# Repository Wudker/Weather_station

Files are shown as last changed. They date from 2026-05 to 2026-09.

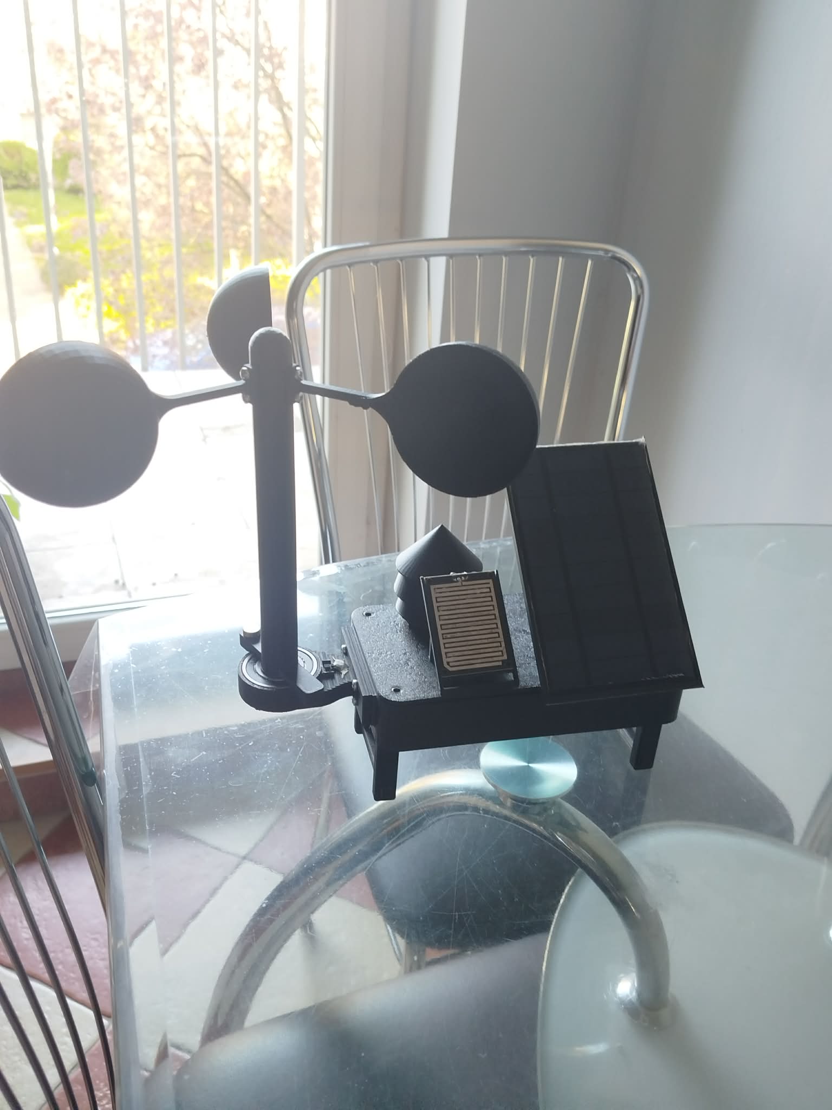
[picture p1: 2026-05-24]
Hardware/Photos/real_model.jpg

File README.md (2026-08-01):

# ESP32 Solar Weather Station

ESP32 Solar Weather Station is a solar-assisted environmental monitoring system consisting of an outdoor measurement module and an indoor receiver. The outdoor unit periodically measures temperature, humidity, atmospheric pressure, wind speed, rainfall, battery voltage and solar-panel voltage. The collected data is transmitted via ESP-NOW to the receiver, which presents current measurements and recent trends through a local web dashboard. RTC-controlled wake-up and sleep modes reduce energy consumption, while a Li-Ion battery and photovoltaic panel support long-term outdoor operation.

## Technologies

`ESP32` `C/C++` `ESP-NOW` `BME280` `SS41F Hall sensor` `Rain sensor` `RTC` `Li-Ion battery` `Photovoltaic power` `ESP32 WebServer` `Low-power operation`

## Usage and development status

Configure the wireless and network parameters, then upload the appropriate firmware to the outdoor and receiver ESP32 modules. After starting both devices, measurements can be accessed through the receiver's local web interface. The current prototype is functional and has been tested; planned improvements include a custom PCB, better enclosure sealing, optimized power management and expanded data visualization.

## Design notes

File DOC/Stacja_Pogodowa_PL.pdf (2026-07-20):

# Projekt „Pogodynka”

Dokumentacja koncowa prototypu ´

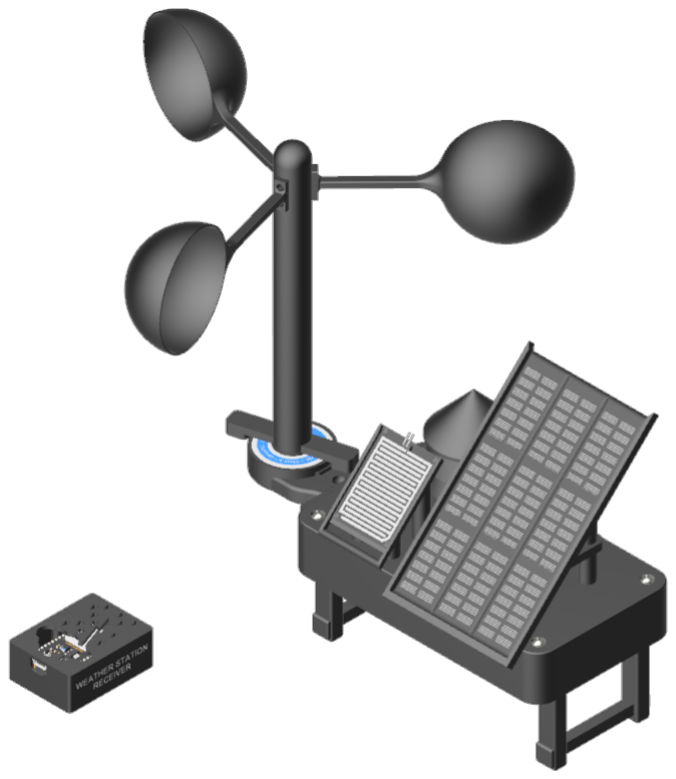
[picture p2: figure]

Autor | Inz. Bartłomiej Dusza ˙
Rewizja | Rev. A
Data | 20 kwietnia 2026
Wersja | 1.0

Niniejszy dokument stanowi podsumowanie etapu realizacji prototypu stacji pogodowej oraz opis jego załoze˙ n, budowy, działania i kierunku dalszego rozwoju. ´

# Spis tresci ´

1 Zało˙zenia projektu | 2
2 Wykonanie prototypu | 6
3 Oprogramowanie i działanie systemu | 9
3.4 Interfejs uzytkownika | ˙ | 10
4 Walidacja prototypu | 11
5 Wnioski i kierunek rozwoju | 12
5.1 Wnioski koncowe | ´ | 12

# Zało˙zenia projektu

## 1.1 Idea i cel urz ˛adzenia

Celem projektu było opracowanie prototypu niewielkiej stacji pogodowej przeznaczonej do pracy zewn˛etrznej, zdolnej do okresowego pomiaru podstawowych parametrów srodowiskowych oraz bezprzewodowego przesyłania wyników do odbiornika. ´

Załozenie projektowe obejmowało wykonanie dwóch współpracuj ˛acych cz˛e ˙ | sci systemu: ´
- modułu pomiarowego umieszczanego na zewn ˛atrz,
- modułu odbiorczego prezentuj ˛acego dane w lokalnej sieci.

Istotnym wymaganiem projektu była mozliwie energooszcz˛edna praca układu oraz ˙ mozliwo ˙ s´c jego dalszej rozbudowy w kolejnych iteracjach. ´

## 1.2 Schemat blokowy systemu

Na rysunku 1.1 przedstawiono ogólny schemat blokowy projektowanego systemu.

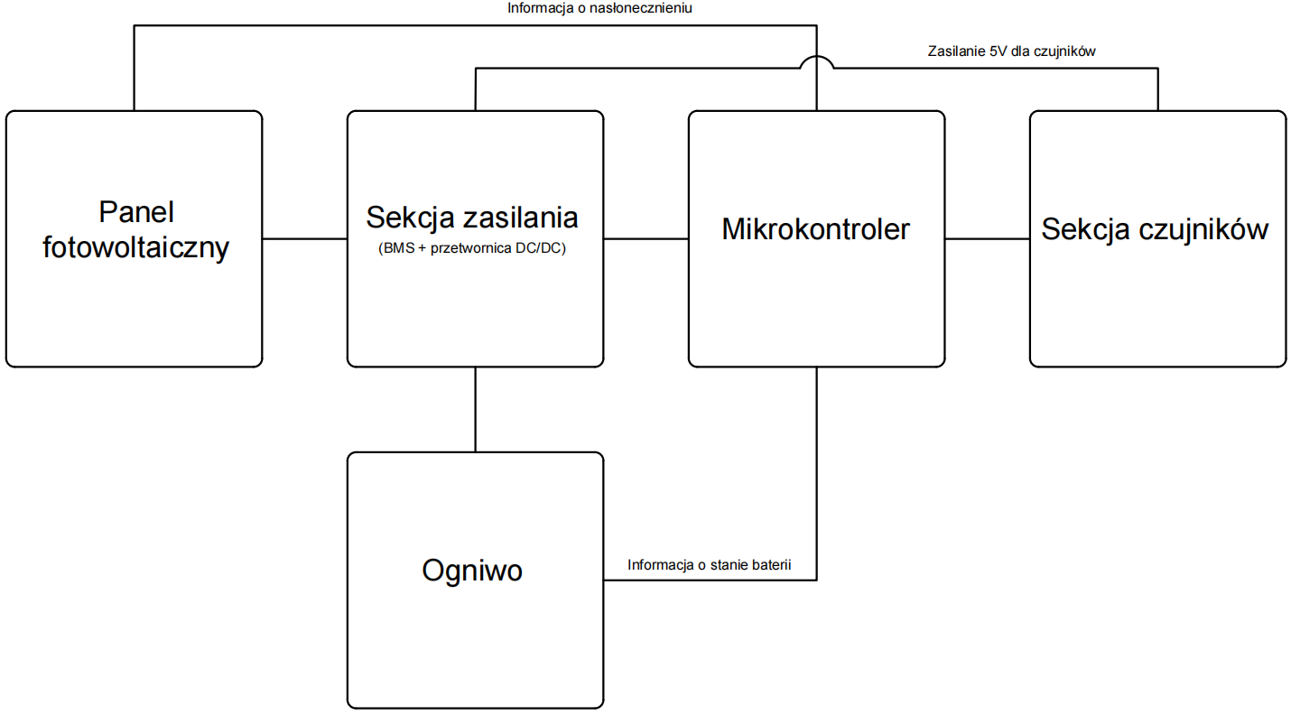
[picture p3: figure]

Rysunek 1.1: Schemat blokowy systemu.

Układ składa si˛e z cz˛esci pomiarowej, modułu steruj ˛acego, toru zasilania oraz cz˛e ´ | sci ´
odbiorczej. Czujniki srodowiskowe s ˛a odczytywane przez mikrokontroler ESP32, który ´

po wykonaniu pomiaru przygotowuje pakiet danych i przesyła go do odbiornika przy pomocy protokołu ESP-NOW. Odbiornik udost˛epnia wyniki w postaci prostej strony internetowej dost˛epnej w sieci lokalnej.

## 1.3 Dobór modułów

Stacja pogodowa musiała umozliwia ˙ | c pomiar podstawowych parametrów atmosferycz- ´
nych, a takze współpracowa ˙ | c z układem zasilanym z ogniwa i panelu fotowoltaicznego. ´
Z tego wzgl˛edu dobrano moduły przedstawione w tabeli 1.1.

Tabela 1.1: Zastosowane moduły i ich funkcje.

Moduł | Funkcja | Interfejs / spo-
sób pracy

Powód wyboru

BME280 | pomiar temperatury,
wilgotnosci i ci ´ | snienia ´

I

2C | integracja trzech
pomiarów w jednym układzie
SGP40 | ocena jakosci powie- ´
trza

I

2C | mozliwo ˙ | s´c rozsze- ´
rzenia funkcjonalnosci o VOC ´
SS41F | pomiar impulsów ane-
mometru
wyjscie cyfrowe ´ | prosty pomiar
pr˛edkosci wiatru ´
Czujnik deszczu | wykrywanie opadów | wyjscie analo- ´
gowe/cyfrowe

niski koszt i łatwos´c integracji ´
ESP32 | sterowanie i transmi-
sja danych

Wi-Fi/ESP-NOW komunikacja bezprzewodowa i wygodna integracja
RTC | wybudzanie czasowe I²C | precyzyjne plano-
wanie cyklu pracy
Panel fotowoltaiczny
zasilanie pomocnicze ´zródło energii | cz˛esciowa samo- ´
wystarczalnos´c´
układu
TP4056 / moduł zasilania
ładowanie ogniwa | tor zasilania | prostota prototy-
powania

### Czujniki srodowiskowe ´

Jako podstawowy sensor srodowiskowy wybrano BME280, który umo ´ | zliwia jednoczesny ˙
pomiar temperatury, wilgotnosci oraz ci ´ | snienia atmosferycznego. ´

Zastosowanie jednego układu do realizacji trzech pomiarów uprosciło konstrukcj˛e oraz ´ ograniczyło liczb˛e poł ˛aczen. Jako uzupełnienie zestawu czujników dobrano SGP40 ´ do oceny jakosci powietrza oraz czujnik Halla SS41F, wykorzystywany do pomiaru ´ pr˛edkosci wiatru na podstawie impulsów generowanych przez obracaj ˛acy si˛e element ´ anemometru.

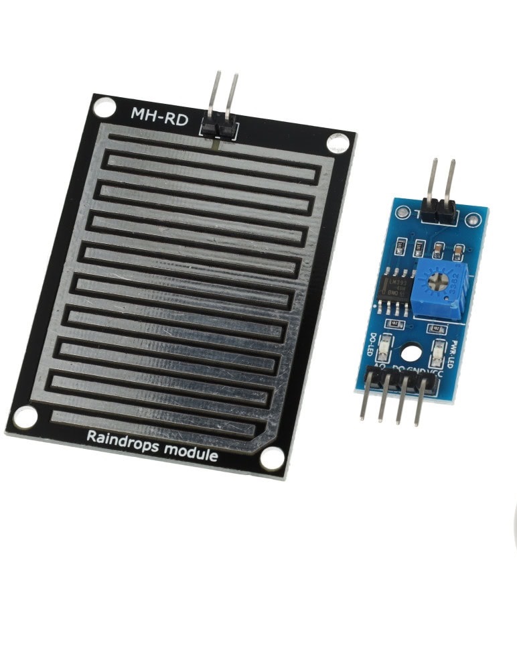
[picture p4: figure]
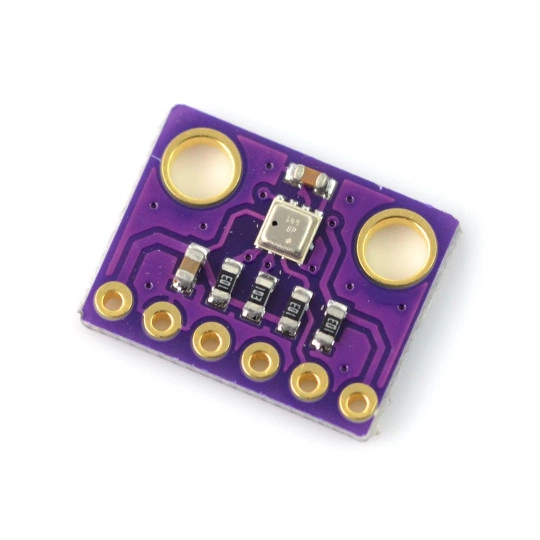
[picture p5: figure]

(a) Moduł czujnika BME280. | (b) Moduł czujnika deszczu.

Rysunek 1.2: Uzupełniaj ˛ace moduły pomiarowe.

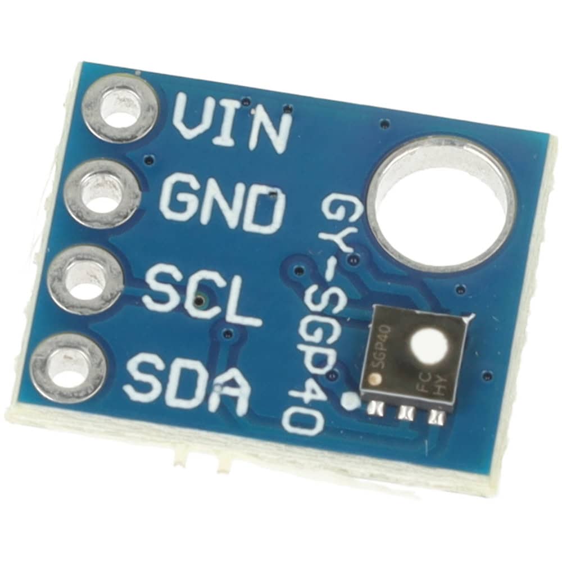
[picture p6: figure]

(a) Moduł SGP40. | (b) Czujnik Halla SS41F.

Rysunek 1.3: Uzupełniaj ˛ace moduły pomiarowe.

Dla mozliwo ˙ | sci wykrywania opadów wykorzystano prosty moduł czujnika deszczu umo ´ | z-˙
liwiaj ˛acy zarówno cyfrow ˛a, jak i analogow ˛a ocen˛e zawilgocenia powierzchni pomiarowej.

### Moduły steruj ˛ace i pomocnicze

Jako główny mikrokontroler zastosowano ESP32, którego zalet ˛a była mozliwo ˙ s´c bez- ´ przewodowej transmisji danych oraz wygodna współpraca z pozostałymi elementami systemu. W celu dokładniejszego planowania cykli pracy układu zastosowano takze˙ zewn˛etrzny moduł RTC.

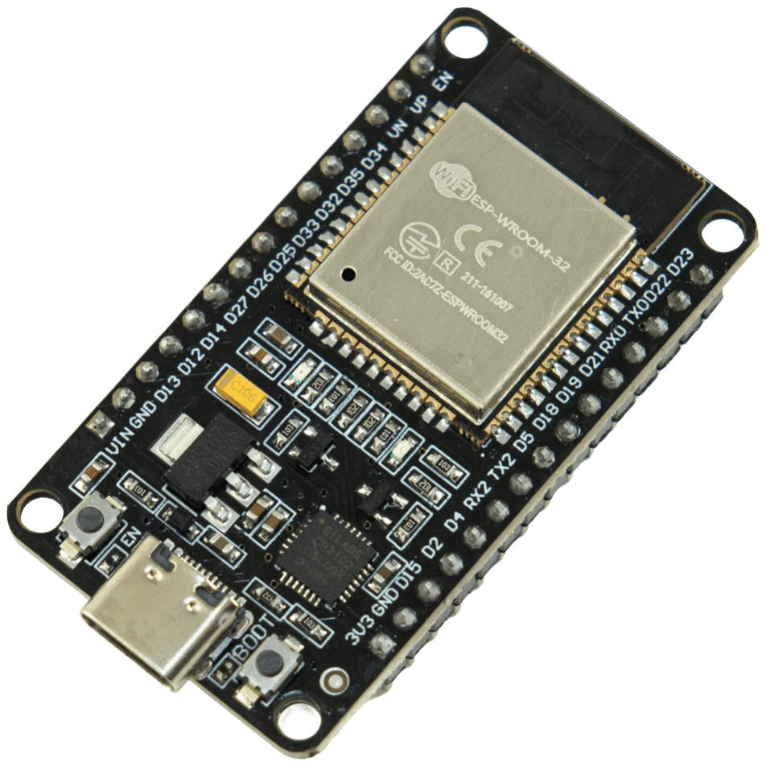
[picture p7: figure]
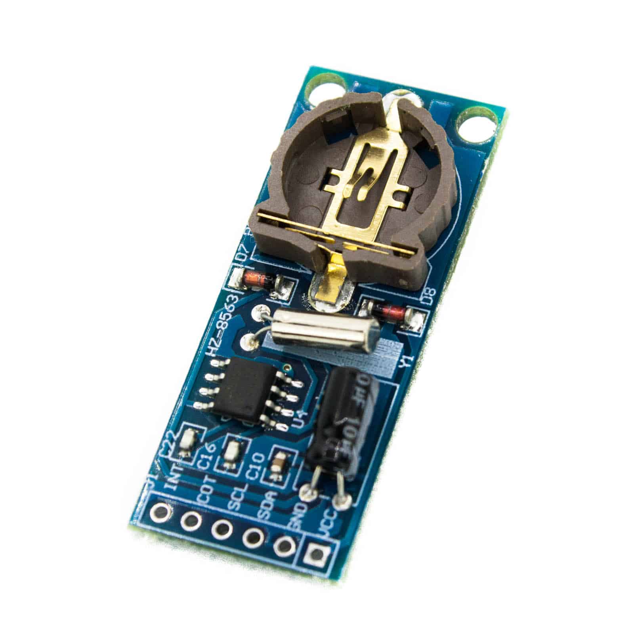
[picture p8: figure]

(a) ESP32. | (b) Moduł RTC.

Rysunek 1.4: Moduły steruj ˛ace.

W cz˛esci prototypowej wykorzystano równie ´ | z moduły pomocnicze, takie jak przetwornica ˙
oraz konwerter poziomów logicznych. Umozliwiały one testowanie ró ˙ | znych wariantów ˙

toru zasilania i uproszczon ˛a integracj˛e elementów pracuj ˛acych z róznymi poziomami ˙ napi˛ec.´

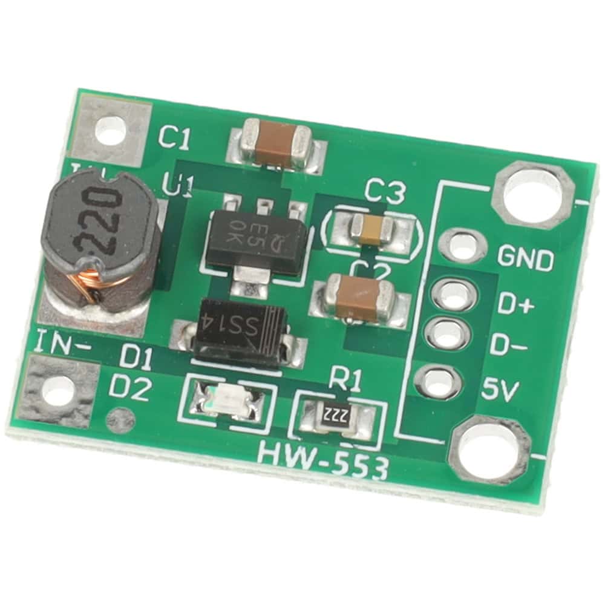
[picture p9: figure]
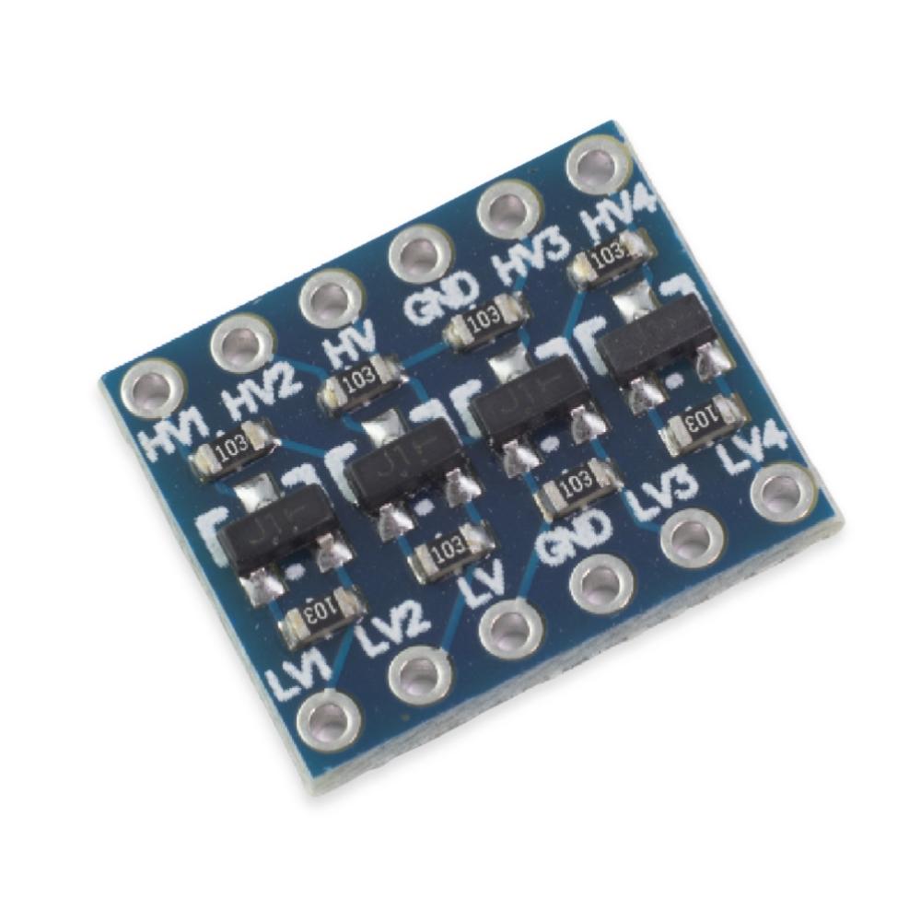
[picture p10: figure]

(a) Przetwornica. | (b) Konwerter poziomów logicznych.

Rysunek 1.5: Moduły pomocnicze zastosowane w prototypie.

### Elementy toru zasilania

Aby umozliwi ˙ | c cz˛e ´ | sciowo autonomiczn ˛a prac˛e stacji, zastosowano panel fotowoltaiczny, ´
ogniwo akumulatorowe oraz moduł ładowania. Dodatkowo napi˛ecie panelu wykorzystano jako przyblizon ˛a informacj˛e o poziomie nasłonecznienia. ˙

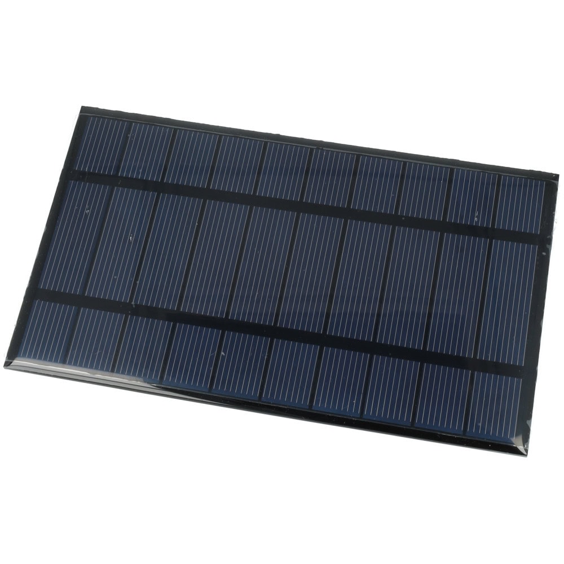
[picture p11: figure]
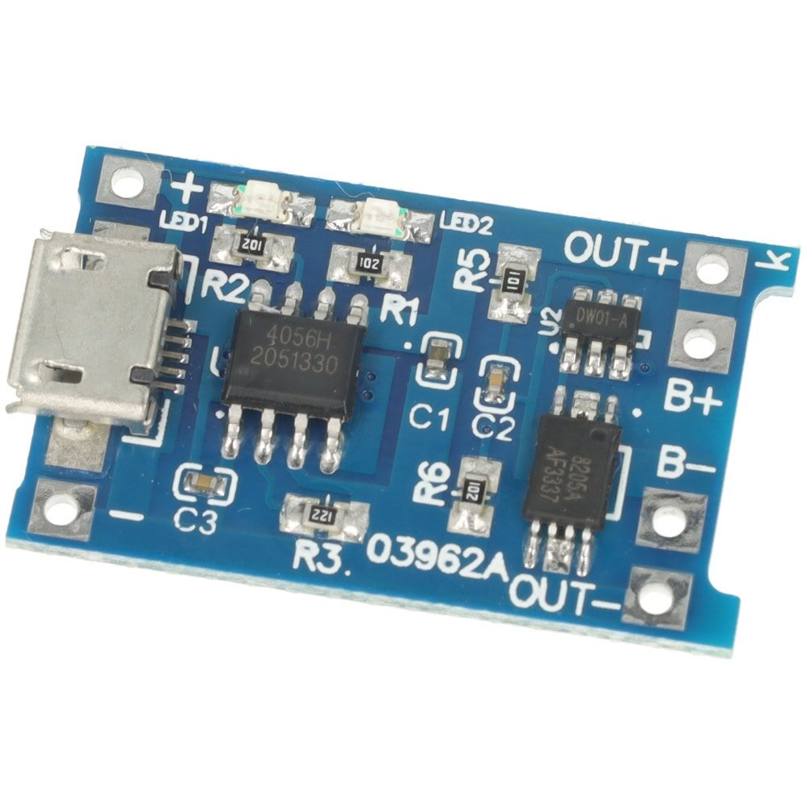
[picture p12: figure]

(a) Panel fotowoltaiczny. | (b) Moduł ładowania ogniwa.

Rysunek 1.6: Elementy toru zasilania.

# Wykonanie prototypu

## 2.1 Mechanika

Głównym celem cz˛esci mechanicznej było zapewnienie ochrony sekcji elektrycznej ´
przed warunkami srodowiskowymi przy jednoczesnym zachowaniu mo ´ | zliwo ˙ | sci pobie- ´
rania danych z otoczenia. Poza obudow ˛a samej stacji wykonano równiez mniejsz ˛a ˙ obudow˛e dla drugiego modułu ESP32, pełni ˛acego funkcj˛e odbiornika.

Model obudowy wykonano w technologii druku 3D z materiału PETG. W celu zwi˛eksze-
nia szczelnosci zastosowano wi˛eksz ˛a liczb˛e ´ | scian oraz stosunkowo niewielk ˛a wysoko ´ | s´c´
warstwy. Z punktu widzenia zastosowania zewn˛etrznego materiał PETG okazał si˛e ko-
rzystny ze wzgl˛edu na odpornos´c na wilgo ´ | c i temperatur˛e. Wło ´ | zono równie ˙ | z wewn ˛atrz ˙
kilka woreczków pochłaniaj ˛acych wilgoc w celu dalszego zabezpieczenia systemu. ´

Do ł ˛aczenia elementów zastosowano wtapiane wkładki gwintowane, natomiast przewody wychodz ˛ace z obudowy zabezpieczono klejem na gor ˛aco. Mocowanie stacji do miejsca
instalacji zaprojektowano w sposób umozliwiaj ˛acy szybki demonta ˙ | z bez u ˙ | zycia narz˛edzi. ˙

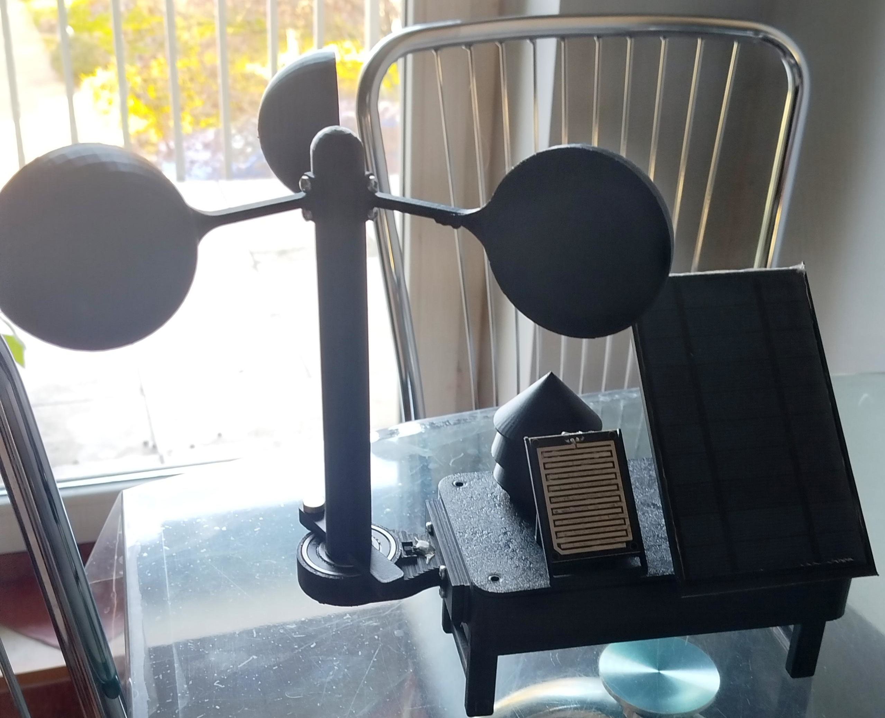
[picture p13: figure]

Rysunek 2.1: Stacja pogodowa w rzeczywistosci. ´

## 2.2 Elektronika

Sekcja elektroniczna musiała zapewnic zarówno poprawn ˛a współprac˛e czujników z ´ ESP32, jak i mozliwo ˙ s´c zasilania układu z ogniwa ładowanego z panelu fotowoltaicz- ´ nego. W wersji prototypowej wykorzystano płytki uniwersalne oraz moduły gotowe, co umozliwiło szybkie uruchomienie i weryfikacj˛e koncepcji. ˙

### 2.2.1 Tor zasilania i gospodarka energetyczna

Tor zasilania obejmował panel fotowoltaiczny, układ ładowania ogniwa, magazyn energii
oraz zasilanie cz˛esci logicznej i pomiarowej. Przyj˛eto zało ´ | zenie, ˙ | ze układ zewn˛etrzny ˙
powinien pracowac cyklicznie i przez wi˛ekszo ´ | s´c czasu pozostawa ´ | c w stanie gł˛ebokiego ´
uspienia, ograniczaj ˛ac pobór energii. ´
W celu poprawy efektywnosci energetycznej znaczn ˛a cz˛e ´ | s´c peryferiów podł ˛aczono do ´
tranzystora MOSFET pracuj ˛acego jako przeł ˛acznik zasilania. Dzi˛eki temu mozliwe było ˙ odł ˛aczanie wybranych elementów na czas uspienia mikrokontrolera. ´

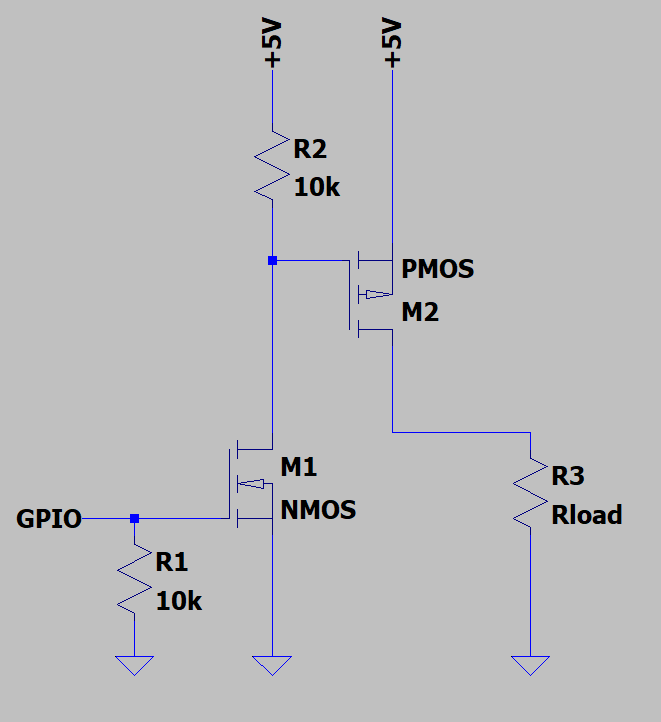
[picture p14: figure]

Rysunek 2.2: Schemat układu odł ˛aczaj ˛acego zasilanie wybranych peryferiów.

Bez zastosowania układu odł ˛aczaj ˛acego pobór pr ˛adu w stanie uspienia wynosił około ´
20 mA. Po wprowadzeniu tego rozwi ˛azania udało si˛e obnizy˙ c pobór do około ´ | 8 mA, co
znacz ˛aco poprawiło teoretyczny czas pracy układu na samym akumulatorze:

3200 mAh
20 mA = 160 h ≈ 6,6 doby

3200 mAh
8 mA = 400 h ≈ 16,6 doby

W praktyce tor zasilania wymaga dalszego dopracowania. Dotyczy to w szczególnosci ´ dokładniejszego monitorowania stanu ogniwa, lepszego wykorzystania energii z panelu fotowoltaicznego oraz ewentualnego zastosowania rozwi ˛azania MPPT w kolejnej wersji projektu.

### 2.2.2 Uwagi dotycz ˛ace czujnika SGP40

Po szczegółowej analizie sposobu pracy czujnika SGP40 zrezygnowano z jego wykorzystania w finalnej wersji prototypu. Mimo ze sam układ nie charakteryzuje si˛e ˙ duzym poborem pr ˛adu chwilowego, to do uzyskania stabilnych i wiarygodnych wyni- ˙ ków wymaga dłuzszego czasu ci ˛agłej pracy. Było to niekorzystne z punktu widzenia ˙ energooszcz˛ednego charakteru stacji.

### 2.2.3 Płytki i poł ˛aczenia prototypowe

W ramach prac wykonano dwie podstawowe sekcje prototypowe: cz˛es´c główn ˛a oraz ´
cz˛es´c zasilania. Poł ˛aczenia mi˛edzy modułami realizowano przewodowo przy u ´ | zyciu ˙
zł ˛acz srubowych i płytek uniwersalnych. ´

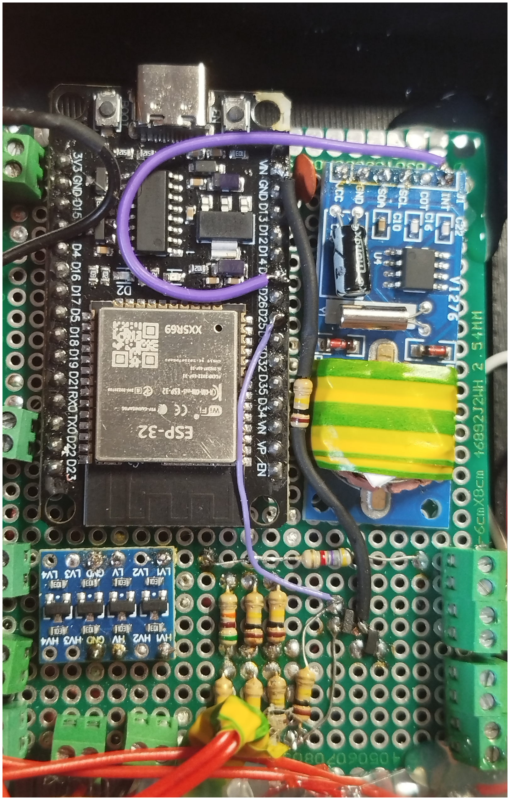
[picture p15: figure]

(a) Płytka główna.

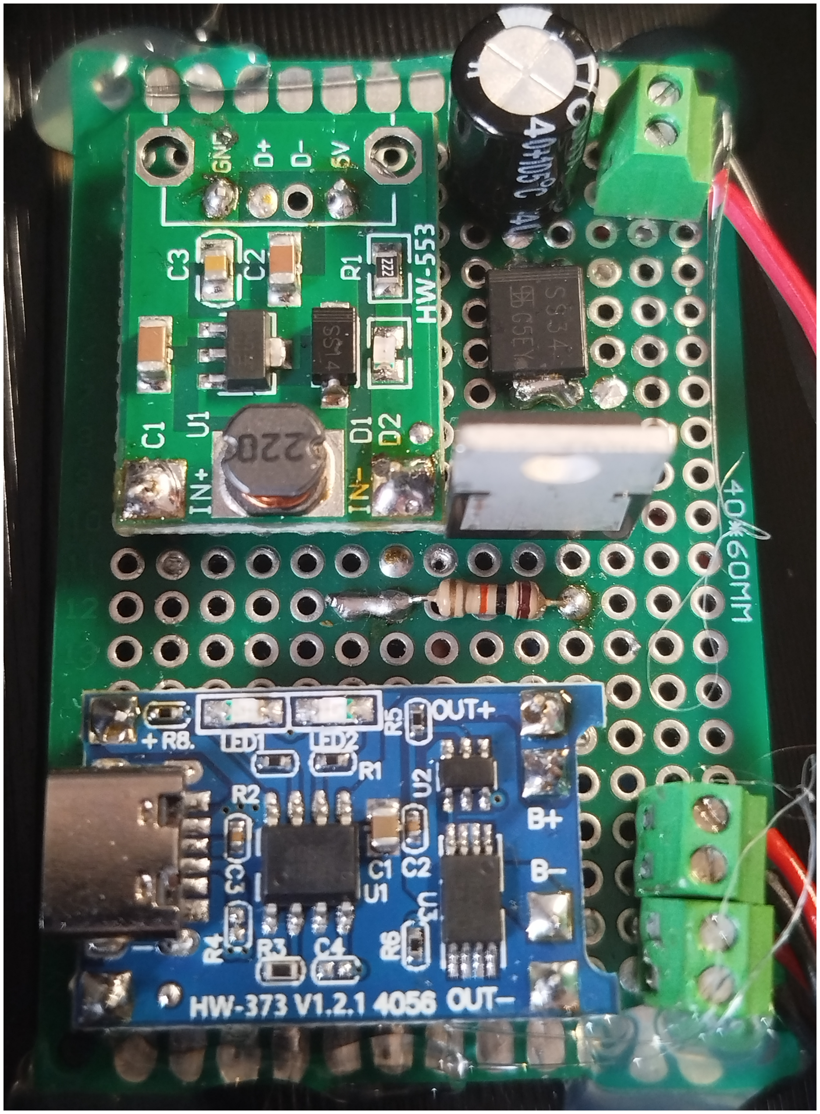
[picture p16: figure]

(b) Płytka zasilania.

Rysunek 2.3: Sekcje prototypowe układu.

# Oprogramowanie i działanie systemu

## 3.1 Ogólna zasada działania

Program stacji pogodowej realizuje cykliczny pomiar parametrów srodowiskowych, ´ przesyła przygotowane dane do odbiornika, a nast˛epnie przechodzi w tryb gł˛ebokiego uspienia. Odbiornik pracuje w sposób ci ˛agły i udost˛epnia ostatnie oraz historyczne dane ´ za posrednictwem prostej strony WWW. ´

## 3.2 Cykl pracy urz ˛adzenia

Na potrzeby projektu przyj˛eto nast˛epuj ˛acy cykl działania modułu zewn˛etrznego:

1. wybudzenie układu z uzyciem RTC, ˙
2. inicjalizacja czujników i niezb˛ednych peryferiów,
3. wykonanie pomiarów srodowiskowych, ´
4. odczyt napi˛ecia baterii i napi˛ecia panelu,
5. przygotowanie pakietu danych,
6. transmisja danych do odbiornika przez ESP-NOW,
7. wył ˛aczenie zb˛ednych elementów peryferyjnych,
8. przejscie mikrokontrolera w tryb ´ | deep sleep.
Takie podejscie pozwala ograniczy ´ | c´ sredni pobór energii i lepiej wykorzysta ´ | c zgroma- ´
dzon ˛a energi˛e akumulatora.

## 3.3 Komunikacja

Komunikacja pomi˛edzy stacj ˛a a odbiornikiem realizowana jest przy pomocy protokołu ESP-NOW. Po wykonaniu pomiaru stacja przygotowuje pakiet danych zawieraj ˛acy aktualne wartosci ´ srodowiskowe i przesyła go do odbiornika. Odbiornik analizuje odebran ˛a ´ struktur˛e danych i aktualizuje wartosci prezentowane na stronie internetowej. ´

Pierwotnie planowano prac˛e odbiornika w trybie punktu dost˛epu, jednak finalnie zdecydowano si˛e na udost˛epnianie strony przez odbiornik działaj ˛acy w lokalnej sieci.
Rozwi ˛azanie to było wygodniejsze z punktu widzenia uzytkownika ko ˙ | ncowego. ´

## 3.4 Interfejs u˙zytkownika

Odbiornik udost˛epnia stron˛e internetow ˛a zawieraj ˛ac ˛a aktualny stan pomiarów oraz
wykres zmian wybranych parametrów w czasie. Dzi˛eki temu uzytkownik mo ˙ | ze odczyta ˙ | c´
nie tylko biez ˛ace dane, ale tak ˙ | ze obserwowa ˙ | c trend temperatury i poziomu naładowania ´
akumulatora.

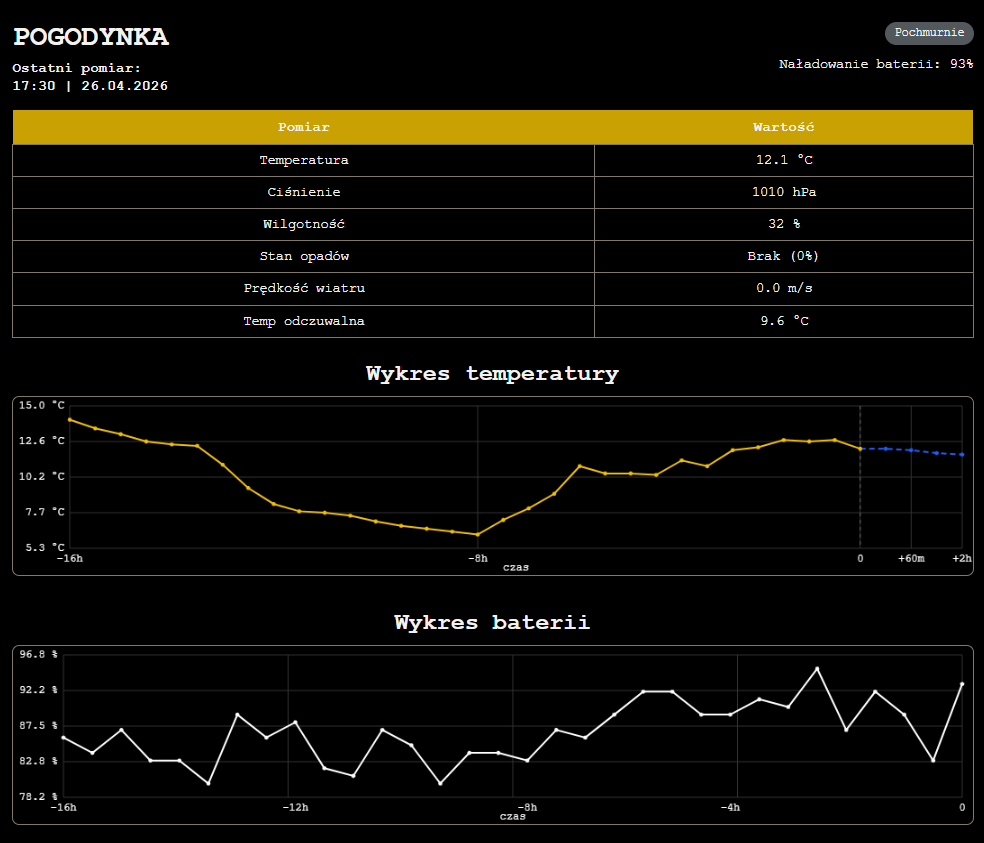
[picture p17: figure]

Rysunek 3.1: Widok strony internetowej odbiornika.

Interfejs został zaprojektowany w mozliwie prostej formie. Prezentowane dane obejmuj ˛a ˙
temperatur˛e, wilgotnos´c, ci ´ | snienie, stan opadów, pr˛edko ´ | s´c wiatru, napi˛ecie akumulatora ´
oraz dodatkowe informacje pomocnicze. Wykorzystano równiez prost ˛a interpolacj˛e, ˙
umozliwiaj ˛ac ˛a bardzo zgrubne przewidywanie temperatury w przyszło ˙ | sci (linia niebieska ´
na wykresie).

# Walidacja prototypu

## 4.1 Metodyka walidacji

Walidacj˛e przeprowadzono poprzez pozostawienie stacji w warunkach rzeczywistych na balkonie przez około miesi ˛ac. W tym czasie obserwowano zachowanie mechaniki,
szczelnos´c obudowy, stabilno ´ | s´c transmisji, poprawno ´ | s´c prezentacji danych oraz ogólne ´
zachowanie toru zasilania.

Test nie miał charakteru pełnej walidacji laboratoryjnej. Jego celem było przede wszystkim potwierdzenie poprawnosci głównej idei działania systemu oraz wskazanie najsłab- ´ szych punktów prototypu wymagaj ˛acych dopracowania.

## 4.2 Zaobserwowane problemy i ograniczenia

W czasie eksploatacji prototypu zaobserwowano nast˛epuj ˛ace problemy:

- anemometr nie działał w sposób w pełni poprawny, co mogło wynikac zarówno ´ z geometrii cz˛esci ruchomej, jak i z warunków przepływu powietrza w miejscu ´ montazu, ˙
- mimo prób poprawy szczelnosci po obfitym deszczu wewn ˛atrz obudowy pojawiły ´ si˛e pojedyncze krople wody,
- poł ˛aczenia przewodów zabezpieczone klejem na gor ˛aco nie stanowi ˛a rozwi ˛azania docelowego i powinny zostac przeprojektowane, ´
- ocena rzeczywistej samowystarczalnosci układu była utrudniona przez niesta- ´
bilnos´c pomiarów napi˛ecia i wpływ warunków ´ | | srodowiskowych na zachowanie ´
ogniwa. Generalnie stacja przez cały czas testowania nie była ani razu ładowana inaczej niz przy pomocy panelu. ˙

# Wnioski i kierunek rozwoju

## 5.1 Wnioski koncowe ´

Wykonany prototyp stacji pogodowej potwierdził mozliwo ˙ s´c budowy prostego, rozpro- ´ szonego systemu pomiarowego opartego na mikrokontrolerach ESP32. Układ umozliwił ˙ realizacj˛e podstawowych pomiarów srodowiskowych, ich bezprzewodow ˛a transmisj˛e ´ oraz prezentacj˛e wyników w lokalnej sieci.

Najwi˛eksze ograniczenia obecnej wersji dotycz ˛a cz˛esci mechanicznej, szczelno ´ | sci ´
obudowy oraz gospodarki energetycznej. Projekt mozna jednak uzna ˙ | c za udany etap ´
weryfikacyjny, stanowi ˛acy dobr ˛a baz˛e do opracowania kolejnej wersji urz ˛adzenia.

## 5.2 Kierunek dalszego rozwoju

W kolejnej wersji projektu zasadne wydaje si˛e:

- przeprojektowanie anemometru i jego cz˛esci ruchomych, ´
- poprawa wodoszczelnosci obudowy oraz przepustów przewodów, ´
- dopracowanie pomiaru napi˛ecia ogniwa i panelu,
- usprawnienie gospodarki energetycznej układu,
- rozwazenie zastosowania układu MPPT lub innego bardziej efektywnego toru ˙ wykorzystania energii z panelu,
- rozbudowa warstwy programowej o bardziej rozwini˛ete metody estymacji lub prognozowania,
- przygotowanie bardziej zwartej wersji elektroniki w postaci dedykowanej płytki PCB.

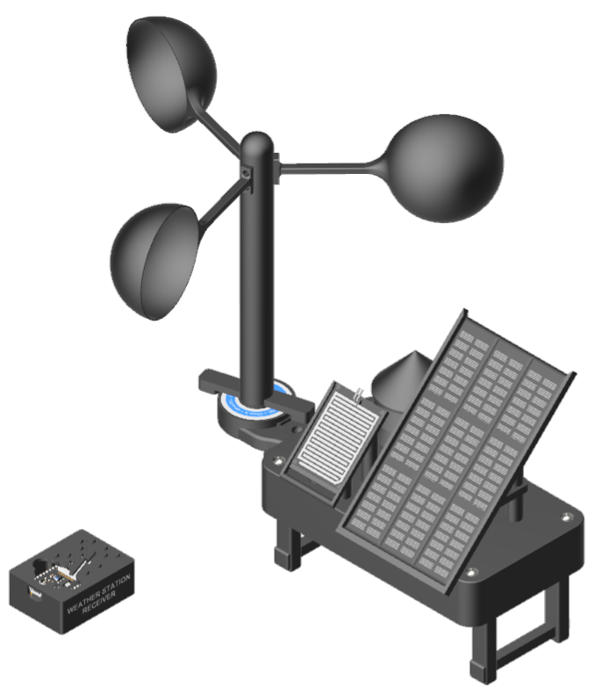
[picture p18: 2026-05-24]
Hardware/Photos/main.png

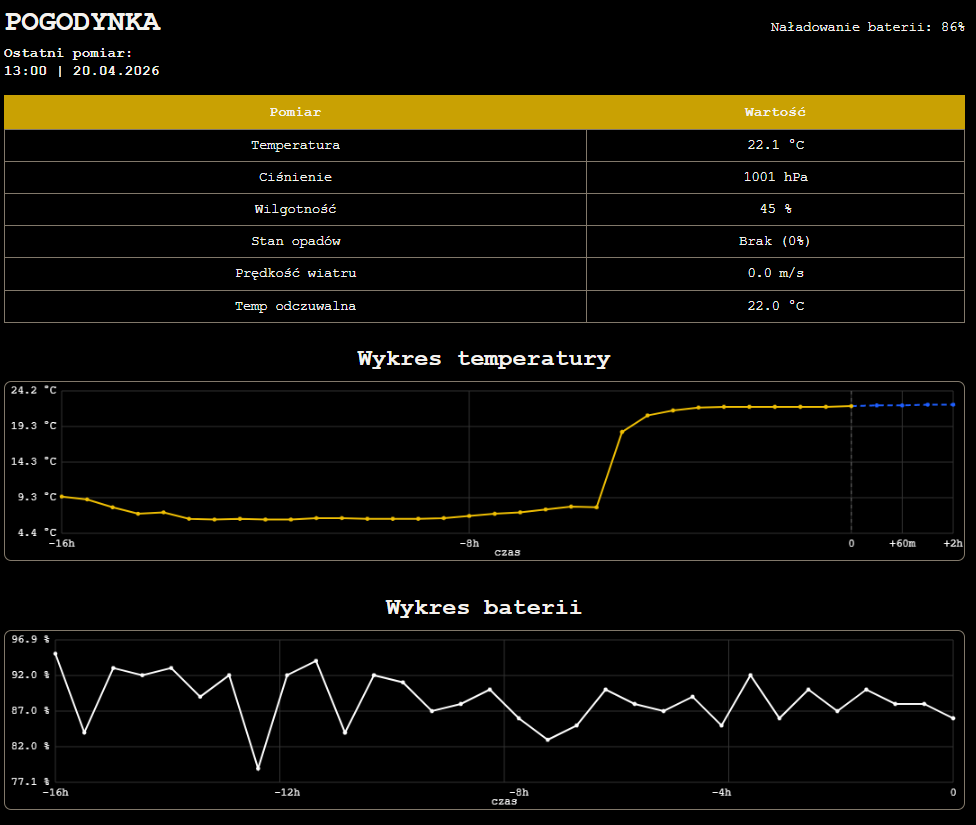
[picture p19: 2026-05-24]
Hardware/Photos/Final_site.png

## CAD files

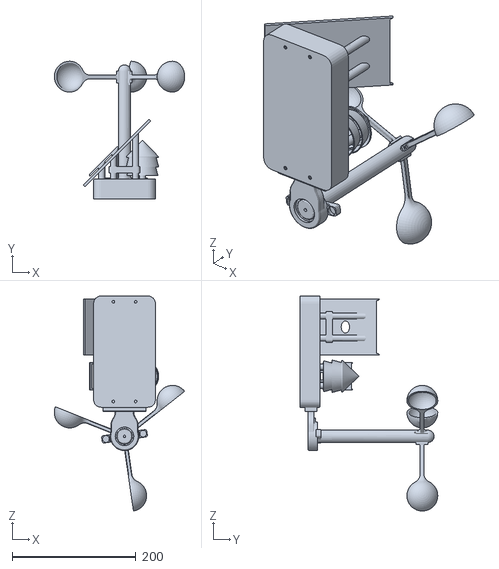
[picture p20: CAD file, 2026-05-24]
Hardware/Model/Station/main.stl
210.9 x 222.6 x 347.8

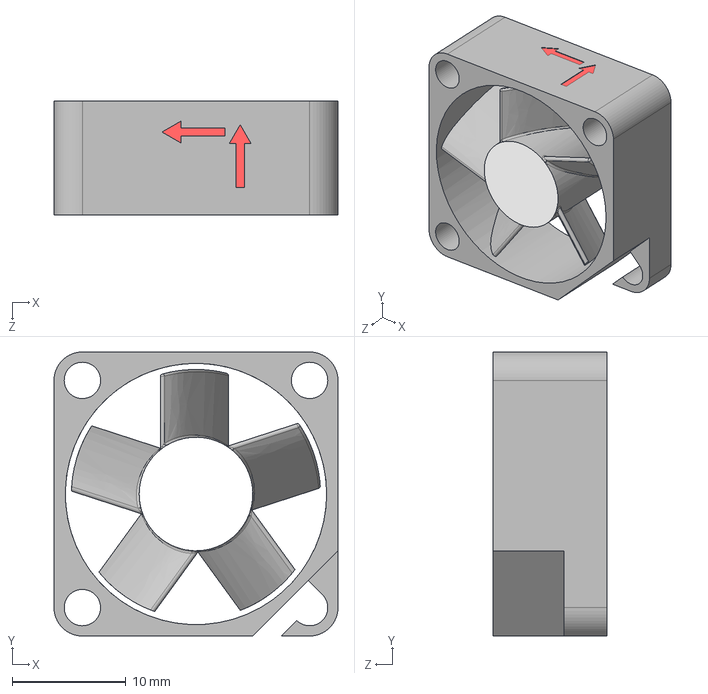
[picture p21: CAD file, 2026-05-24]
Hardware/Model/Reciever/25MM SUNON FAN .STEP
25.0 x 25.0 x 10.0 mm

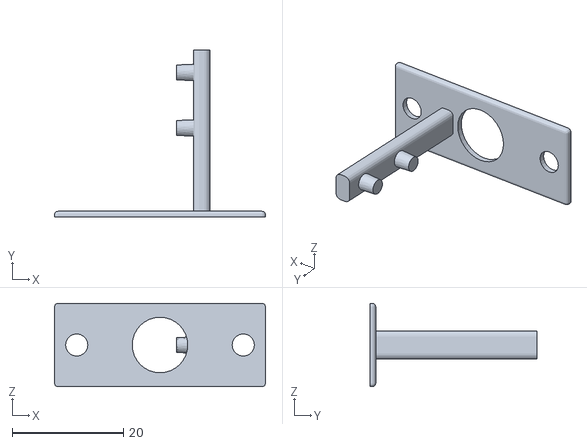
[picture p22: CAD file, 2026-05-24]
Hardware/Model/Station/sensor_holder.stl
38.0 x 30.0 x 15.0

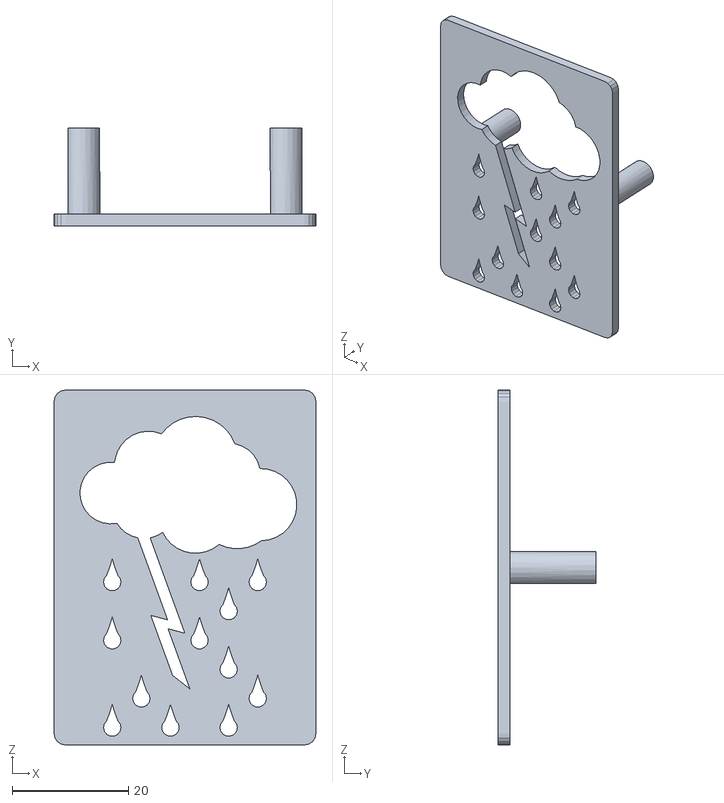
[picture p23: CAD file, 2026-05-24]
Hardware/Model/Reciever/Odbiornik_top.stl
45.0 x 16.8 x 61.0

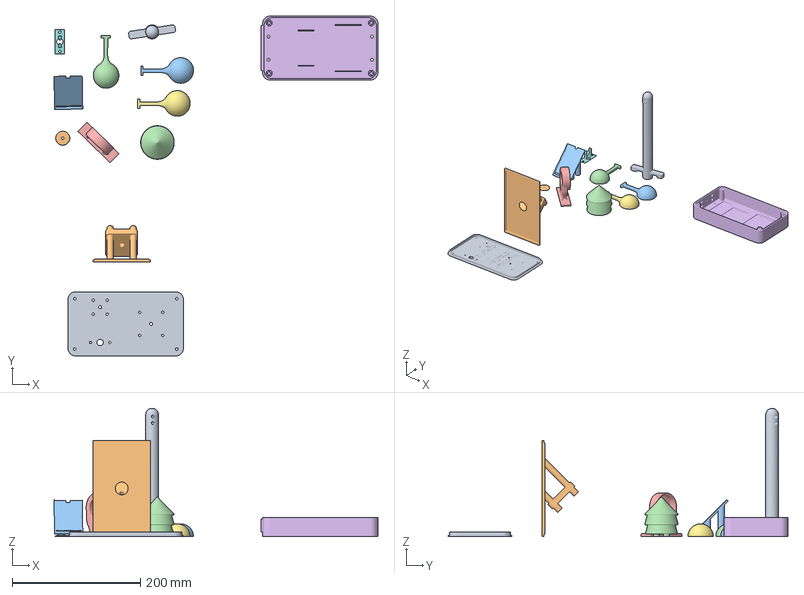
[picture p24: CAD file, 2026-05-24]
Hardware/Model/Station/Stacja_calosc.3mf
504.9 x 529.7 x 200.0 mm
main.stl_4
main.stl_8
main.stl_9
main.stl_11
main.stl_3
main.stl_1
main.stl_7 x 3
main.stl_10
main.stl_2
main.stl_12

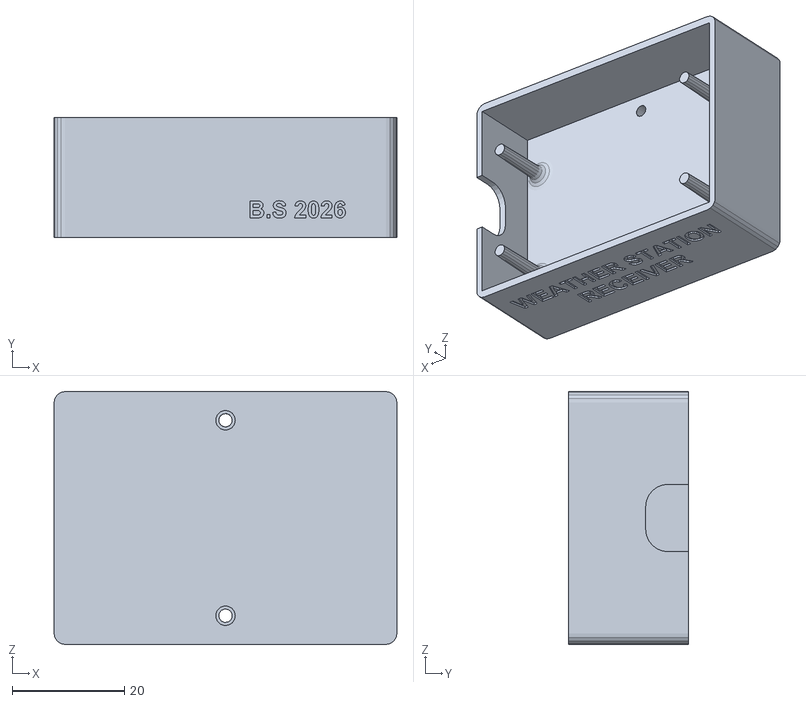
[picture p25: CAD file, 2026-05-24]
Hardware/Model/Reciever/Odbiornik_bot.stl
61.0 x 21.3 x 45.0

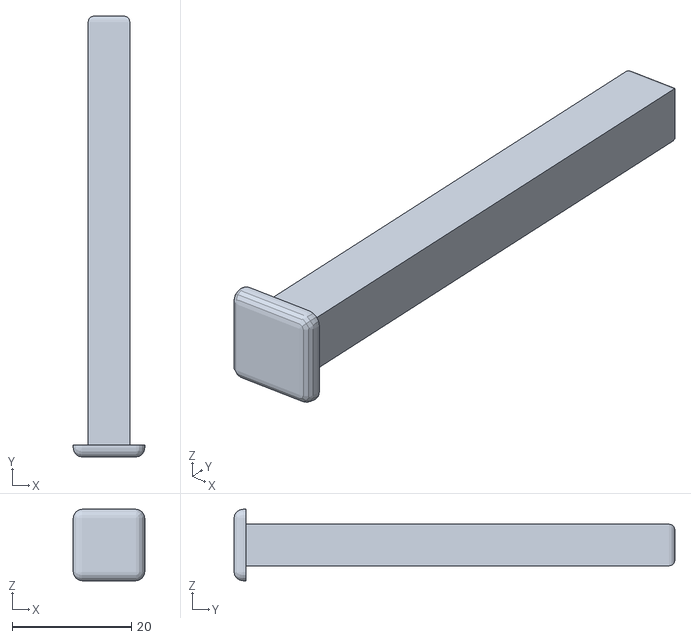
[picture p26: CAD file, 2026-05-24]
Hardware/Model/Station/kołek.stl
12.0 x 74.0 x 12.0

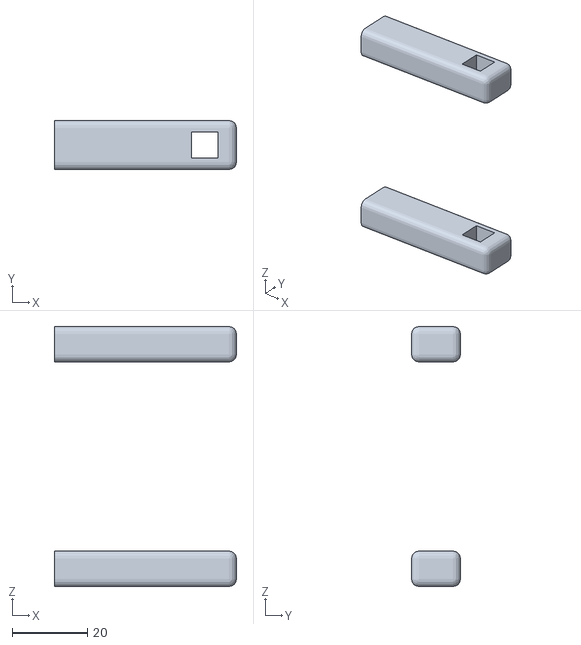
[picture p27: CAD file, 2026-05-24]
Hardware/Model/Station/clamp.stl
48.3 x 13.0 x 69.0

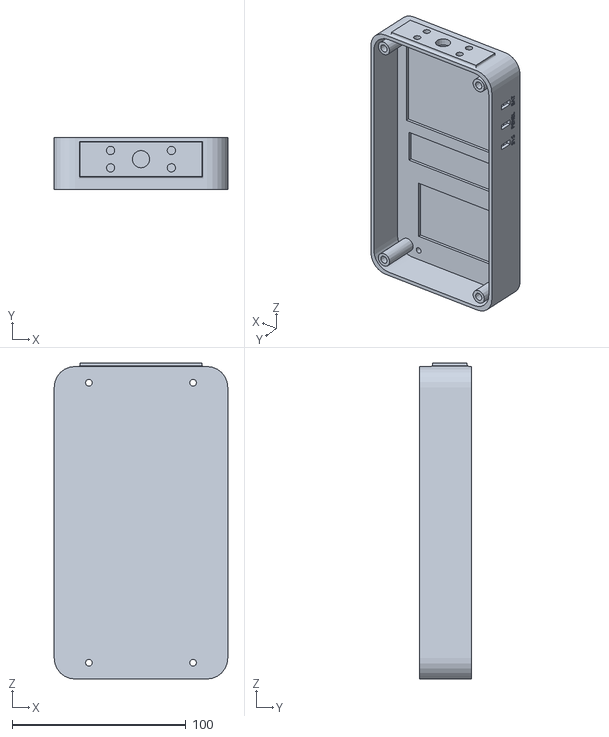
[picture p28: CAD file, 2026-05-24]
Hardware/Model/Station/spod.stl
100.0 x 30.0 x 182.0

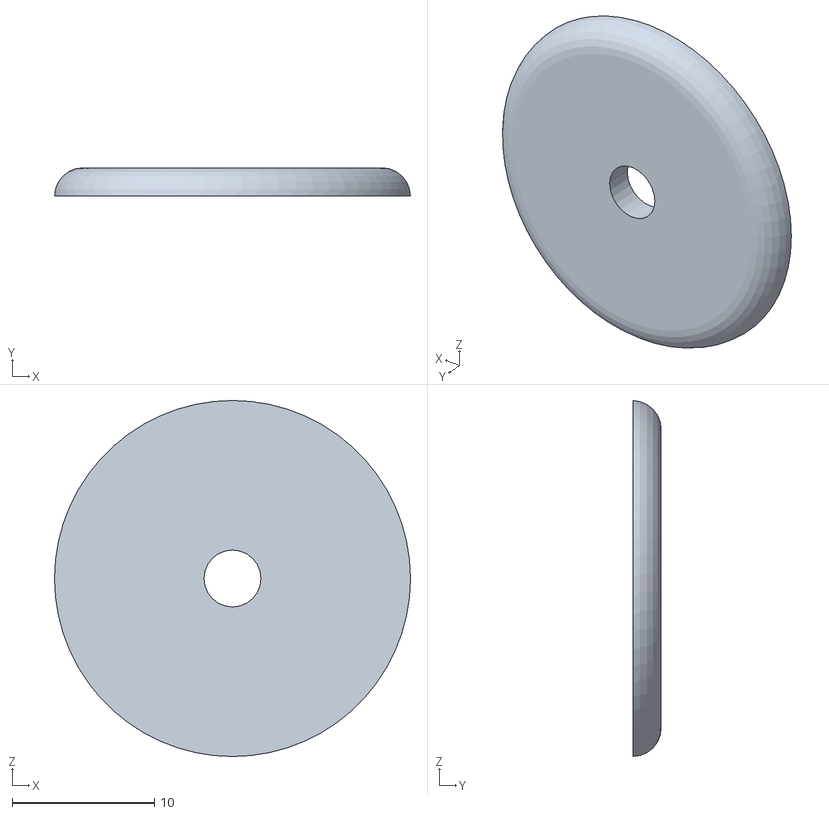
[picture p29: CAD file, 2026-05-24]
Hardware/Model/Station/tarcza_wal.stl
25.0 x 2.00 x 25.0

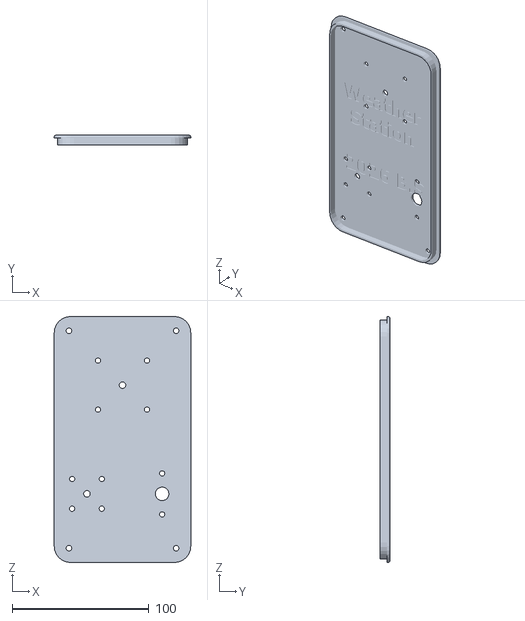
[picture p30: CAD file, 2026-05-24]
Hardware/Model/Station/gora.stl
100.0 x 7.00 x 180.0

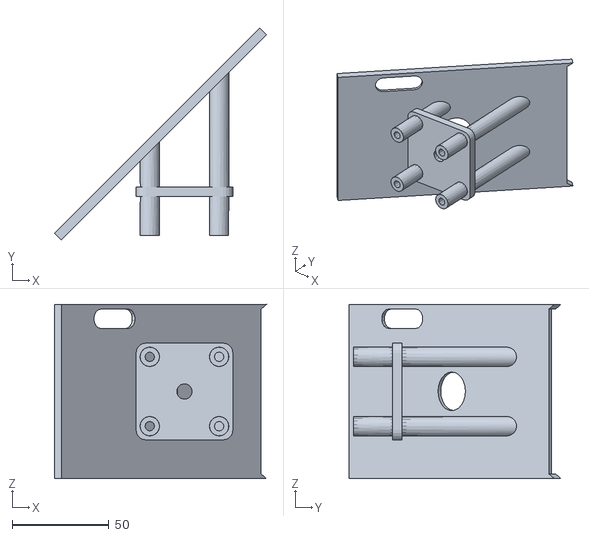
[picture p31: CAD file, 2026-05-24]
Hardware/Model/Station/solar_stand.stl
109.6 x 109.6 x 90.0

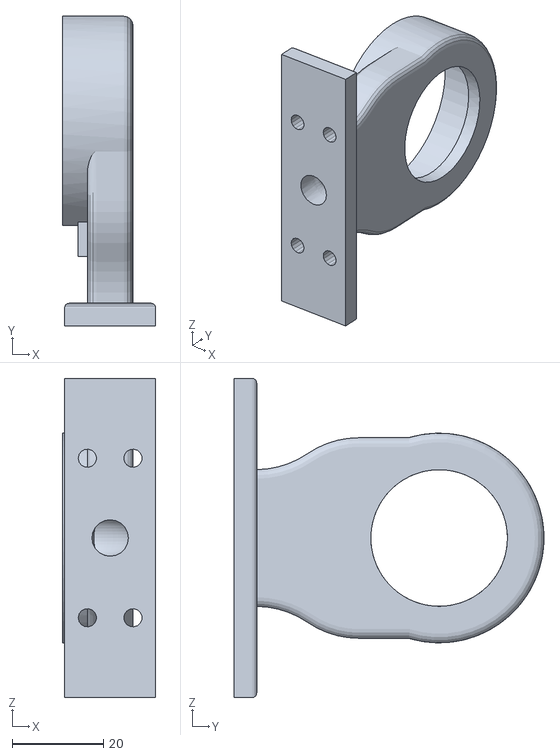
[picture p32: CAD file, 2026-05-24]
Hardware/Model/Station/anomierz_rama.stl
20.5 x 68.0 x 70.0

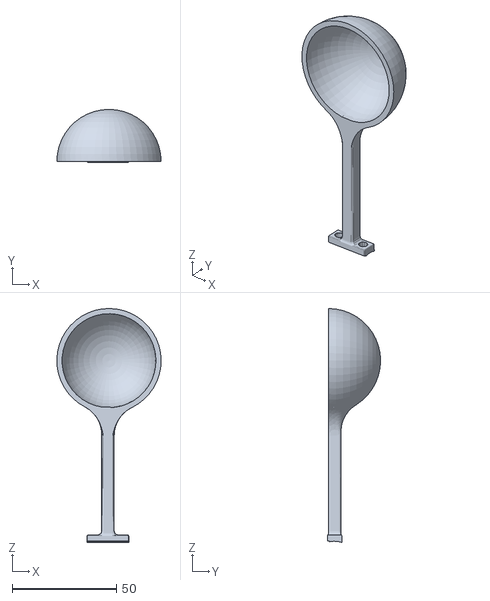
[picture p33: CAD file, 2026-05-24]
Hardware/Model/Station/czasza.stl
50.0 x 25.5 x 112.1

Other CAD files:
Hardware/Model/Station/ul.stl
Hardware/Model/Station/UL2.stl
Hardware/Model/Reciever/ESP32 WROOM.ipt
Hardware/Model/Reciever/Odbiornik_bot.ipt
Hardware/Model/Reciever/Odbiornik_top.ipt
Hardware/Model/Reciever/OldVersions/Odbiornik_bot.0004.ipt
Hardware/Model/Reciever/OldVersions/Odbiornik_top.0005.ipt
Hardware/Model/Station/92000A228_Passivated 18-8 Stainless Steel Pan Head Phillips Screws.ipt
Hardware/Model/Station/97164A115_Aluminum Tapered Heat-Set Inserts for Plastic.ipt
Hardware/Model/Station/SolarPanel_30x65x3mm.ipt
Hardware/Model/Station/UL2.ipt
Hardware/Model/Station/andomierz_wal.ipt
Hardware/Model/Station/anomierz_rama.ipt
Hardware/Model/Station/clamp.ipt
Hardware/Model/Station/czasza.ipt
Hardware/Model/Station/gora.ipt
Hardware/Model/Station/hoja v2.ipt
Hardware/Model/Station/kołek.ipt
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

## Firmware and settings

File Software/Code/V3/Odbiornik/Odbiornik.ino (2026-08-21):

#include <WiFi.h>
#include <esp_now.h>
#include <WebServer.h>
#include <ESPmDNS.h>
#include <SPI.h>
#include <SD.h>
#include <math.h>
#include <time.h>
#include "PogodynkaRxTypes.h"
#include "Secret_keys.h"
#include "MQTT.h"

WebServer server(80);

static const int History_size = 32;
static const int Forecast_size = 4;

static const int TIME_OFFSET_HOURS = 0;

// Proponowane piny karty SD dla klasycznego ESP32 / ESP32 DevKit:
// CS  -> GPIO5
// SCK -> GPIO18
// MISO-> GPIO19
// MOSI-> GPIO23
// Zasilanie modułu SD: 3.3 V, wspólna masa GND.
static const int SD_CS_PIN   = 5;
static const int SD_SCK_PIN  = 18;
static const int SD_MISO_PIN = 19;
static const int SD_MOSI_PIN = 23;
// Pliki logow sa tworzone osobno dla kazdego miesiaca, np. /pogodynka_2026_04.csv.
// Jeden plik obejmuje dni od 1 do konca danego miesiaca.

Dane_ESP Dane;

static float Historia_Temperatury[History_size];
static float Prognoza_Temperatury[Forecast_size];
static float Historia_Bateri[History_size];
static float Historia_Opady[History_size];

static uint32_t lastRxMs = 0;
static uint16_t historia_ilosc = 0;

static bool sd_ok = false;
static volatile bool sd_log_pending = false;
static Dane_ESP Dane_do_zapisu;
static volatile bool mqtt_publish_pending = false;
static Dane_ESP Dane_do_mqtt;

static bool wifi_laczenie = false;
static bool wifi_bylo_polaczone = false;
static uint32_t wifi_start_ms = 0;
static uint32_t wifi_next_attempt_ms = 0;
static uint32_t wifi_retry_delay_ms = 5000;
static const uint32_t WIFI_CONNECT_TIMEOUT_MS = 15000;
static const uint32_t WIFI_RETRY_INITIAL_MS = 5000;
static const uint32_t WIFI_RETRY_MAX_MS = 60000;

static bool mdns_ok = false;

static const char* NTP_TZ = "CET-1CEST,M3.5.0/2,M10.5.0/3";
static const char* NTP_SERVER_1 = "pl.pool.ntp.org";
static const char* NTP_SERVER_2 = "pool.ntp.org";
static const char* NTP_SERVER_3 = "time.google.com";
static const time_t NTP_MIN_VALID_EPOCH = 1704067200;
static const uint32_t NTP_CHECK_PERIOD_MS = 1000;
static const uint32_t NTP_LOG_GRACE_MS = 15000;

static bool ntp_uruchomiony = false;
static bool ntp_gotowy = false;
static uint32_t ntp_last_check_ms = 0;
static volatile uint32_t sd_log_pending_since_ms = 0;
static volatile uint32_t mqtt_publish_pending_since_ms = 0;

static const char INDEX_HTML[] PROGMEM = R"rawliteral(
  <!DOCTYPE html>
  <html lang="pl">
  <head>
    <meta charset="utf-8" />
    <meta name="viewport" content="width=device-width, initial-scale=1" />
    <title>Pogodynka</title>
    <style>
      :root{ --maxw: 1100px; --gap: 16px; --yellow: #EFBF04; }
      *{ box-sizing: border-box; }
      body{ margin:0; padding:12px; font-family:"Courier New", monospace; text-align:center; background:#000; color:#fff; }
      .page{ width:min(100%, var(--maxw)); margin:0 auto; padding:16px; }
      .top{ display:flex; align-items:flex-start; justify-content:space-between; gap:var(--gap); flex-wrap:nowrap; }
      .logo{ flex:0 0 260px; text-align:left; }
      .logo h2{ margin:0 0 6px 0; font-size:clamp(20px, 3vw, 32px); line-height:1.1; }
      .logo h5{ margin:0; font-size:clamp(12px, 1.6vw, 16px); line-height:1.25; font-weight:600; }
      .summary{ flex:1 1 auto; min-width:0; text-align:right; }
      .badges{ display:flex; gap:8px; justify-content:flex-end; flex-wrap:wrap; overflow-x:auto; -webkit-overflow-scrolling:touch; padding-bottom:4px; }
      .badge{ display:inline-block; padding:6px 10px; border-radius:999px; font-size:clamp(11px, 1.2vw, 13px); line-height:1; white-space:nowrap; flex:0 0 auto; color:#000; background:#ddd; }
      .b-yellow{ background:#EFBF04; }
      .b-red{ background:#ff3b30; color:#fff; }
      .b-blue{ background:#1e5eff; color:#fff; }
      .b-green{ background:#18c964; }
      .b-gray{ background:#9aa0a6; }
      .b-orange{ background:#ff9f0a; }
      .b-lightblue{ background:#7dd3fc; }
      .hidden{ display:none; }
      .battery{ margin-top:10px; font-size:clamp(12px, 1.4vw, 15px); text-align:right; }
      table{ width:100%; border-collapse:collapse; margin:16px auto; }
      th{ padding:10px; background:var(--yellow); color:#000; font-weight:700; }
      td{ padding:9px; border:1px solid #333; font-size:15px; }
      .chart{ width:100%; margin:10px auto 18px auto; padding:10px 0; }
      .chart h1{ margin:0 0 10px 0; font-size:clamp(18px, 2.4vw, 26px); font-weight:700; }
      canvas{ width:100%; height:200px; border:1px solid #333; border-radius:8px; display:block; }
      @media (min-width:900px){ .badges{ flex-wrap:wrap; overflow-x:visible; } }
      @media (max-width:520px){
        body{ padding:10px; }
        .page{ padding:12px; }
        .top{ flex-direction:column; align-items:stretch; }
        .logo{ flex:1 1 auto; }
        .summary{ text-align:left; }
        .badges{ justify-content:flex-start; }
        .battery{ text-align:left; }
        td{ font-size:14px; }
      }
    </style>
  </head>
  <body>
    <div class="page">
      <div class="top">
        <div class="logo">
          <h2>POGODYNKA</h2>
          <h5>Ostatni pomiar:<br><span id="last">--:-- | --.--.----</span></h5>
        </div>
        <div class="summary">
          <div class="badges">
            <span class="badge b-yellow hidden" id="bd_sun">Słonecznie</span>
            <span class="badge b-blue hidden" id="bd_rain">Deszcz</span>
            <span class="badge b-gray hidden" id="bd_cloud">Pochmurnie</span>
            <span class="badge b-orange hidden" id="bd_wind">Wietrznie</span>
            <span class="badge b-lightblue hidden" id="bd_cold">Zimno</span>

            <span class="badge b-blue hidden" id="bd_humid">Wilgotno</span>
            <span class="badge b-gray hidden" id="bd_dry">Sucho</span>

            <span class="badge b-orange hidden" id="bd_batt_low">Niski stan baterii</span>
            <span class="badge b-red hidden" id="bd_batt_crit">Krytyczna bateria</span>

            <span class="badge b-gray hidden" id="bd_pres_low">Niskie ciśnienie</span>
            <span class="badge b-yellow hidden" id="bd_pres_high">Wysokie ciśnienie</span>
          </div>
          <div class="battery">Naładowanie baterii: <span id="Batt_procent">--</span>%</div>
        </div>
      </div>

      <table>
        <tr><th>Pomiar</th><th>Wartość</th></tr>
        <tr><td>Temperatura</td><td><span id="temp">--</span> °C</td></tr>
        <tr><td>Ciśnienie</td><td><span id="pres">--</span> hPa</td></tr>
        <tr><td>Wilgotność</td><td><span id="hum">--</span> %</td></tr>
        <tr><td>Stan opadów</td><td><span id="rainState">--</span></td></tr>
        <tr><td>Prędkość wiatru</td><td><span id="wind">--</span> m/s</td></tr>
        <tr><td>Temp odczuwalna</td><td><span id="feels">--</span> °C</td></tr>
      </table>

      <div class="chart">
        <h1>Wykres temperatury</h1>
        <canvas id="chartTemp"></canvas>
      </div>

      <div class="chart">
        <h1>Wykres baterii</h1>
        <canvas id="chartBatt"></canvas>
      </div>
    </div>

  <script>
    const DT_MIN = 30;

    let rainDryMV = 200;
    let rainWetMV = 1200;

    function $(id){ return document.getElementById(id); }
    function pad2(x){ x = Number(x)||0; return (x<10?'0':'') + x; }
    function showBadge(id, show){
      const el = $(id);
      if(!el) return;
      el.classList.toggle('hidden', !show);
    }

    function resizeCanvas(c, h){
      const w = c.clientWidth || 300;
      const dpr = window.devicePixelRatio || 1;
      c.width = Math.floor(w * dpr);
      c.height = Math.floor(h * dpr);
      c.style.height = h + 'px';
      const ctx = c.getContext('2d');
      ctx.setTransform(dpr,0,0,dpr,0,0);
      return {ctx, w, h};
    }

    function fmtTime(mins){
      if(mins === 0) return "0";
      const sign = mins > 0 ? "+" : "-";
      const a = Math.abs(mins);
      if(a >= 120){
        const h = Math.round(a/60);
        return sign + h + "h";
      }
      return sign + a + "m";
    }

    function clamp(x, a, b){ return Math.max(a, Math.min(b, x)); }

    function calcApparentTempC(Tc, RH, windMs){
      const e = (RH/100.0) * 6.105 * Math.exp((17.27*Tc)/(237.7+Tc));
      return Tc + 0.33*e - 0.70*windMs - 4.00;
    }

    function calcWindChillC(Tc, windMs){
      const v = windMs * 3.6;
      const p = Math.pow(v, 0.16);
      return 13.12 + 0.6215*Tc - 11.37*p + 0.3965*Tc*p;
    }

    function calcHeatIndexC(Tc, RH){
      const Tf = Tc * 9/5 + 32;
      const HI =
        -42.379 +
        2.04901523*Tf +
        10.14333127*RH +
        -0.22475541*Tf*RH +
        -0.00683783*Tf*Tf +
        -0.05481717*RH*RH +
        0.00122874*Tf*Tf*RH +
        0.00085282*Tf*RH*RH +
        -0.00000199*Tf*Tf*RH*RH;
      return (HI - 32) * 5/9;
    }

    function calcFeelsLikeC(Tc, RH, windMs){
      if(Tc <= 10 && windMs >= 1.34) return calcWindChillC(Tc, windMs);
      if(Tc >= 27 && RH >= 40) return calcHeatIndexC(Tc, RH);
      return calcApparentTempC(Tc, RH, windMs);
    }

    function movingAverage(data, windowSize){
      if(!Array.isArray(data)) return [];
      const n = Math.max(1, Number(windowSize) || 1);
      const out = [];

      for(let i=0; i<data.length; i++){
        let sum = 0;
        let count = 0;

        for(let j=Math.max(0, i-n+1); j<=i; j++){
          const v = Number(data[j]);
          if(isFinite(v)){
            sum += v;
            count++;
          }
        }

        out.push(count ? (sum / count) : null);
      }

      return out;
    }

    function drawLineChart(canvasId, data, yUnit, dtMin){
      const c = $(canvasId);
      if(!c || !data || data.length < 2) return;

      const H = 200;
      const {ctx, w, h} = resizeCanvas(c, H);

      ctx.clearRect(0,0,w,h);

      const arr = data.map(v => (v===null || v===undefined) ? NaN : Number(v));
      const valid = arr.filter(v => isFinite(v));
      if(valid.length < 2) return;

      let min = Math.min(...valid);
      let max = Math.max(...valid);
      let pad = (max - min) * 0.12;
      if(pad === 0) pad = 1;
      min -= pad; max += pad;

      ctx.fillStyle = "#fff";
      ctx.font = "12px Courier New";

      const yLabels = [];
      for(let i=0;i<=4;i++){
        const val = (max - (max-min) * (i/4));
        const txt = (Math.abs(val) >= 100 ? val.toFixed(0) : val.toFixed(1)) + " " + yUnit;
        yLabels.push(txt);
      }
      const maxLabelW = Math.max(...yLabels.map(t => ctx.measureText(t).width));

      const mL = Math.max(48, Math.ceil(maxLabelW) + 12);
      const mR = 12, mT = 10, mB = 30;

      const plotW = Math.max(10, w - mL - mR);
      const plotH = Math.max(10, h - mT - mB);

      const n = arr.length;

      function mapX(i){ return mL + plotW * (i/(n-1)); }
      function mapY(v){ return mT + plotH - plotH * ((v - min) / (max - min)); }

      ctx.strokeStyle = "#333";
      ctx.lineWidth = 1;
      for(let i=0;i<=4;i++){
        const y = mT + (plotH * i / 4);
        ctx.beginPath(); ctx.moveTo(mL,y); ctx.lineTo(mL+plotW,y); ctx.stroke();
      }
      for(let i=0;i<=4;i++){
        const x = mL + (plotW * i / 4);
        ctx.beginPath(); ctx.moveTo(x,mT); ctx.lineTo(x,mT+plotH); ctx.stroke();
      }

      ctx.fillStyle = "#fff";
      ctx.font = "12px Courier New";

      ctx.textAlign = "right";
      ctx.textBaseline = "middle";
      for(let i=0;i<=4;i++){
        const y = mT + (plotH * i / 4);
        ctx.fillText(yLabels[i], mL - 6, y);
      }

      ctx.textAlign = "center";
      ctx.textBaseline = "top";
      for(let i=0;i<=4;i++){
        const idx = Math.round((n-1) * (i/4));
        const x = mapX(idx);
        const mins = (idx - (n-1)) * (dtMin || DT_MIN);
        ctx.fillText(fmtTime(mins), x, mT + plotH + 6);
      }

      ctx.textAlign = "center";
      ctx.textBaseline = "bottom";
      ctx.fillText("czas", mL + plotW/2, h - 2);

      ctx.strokeStyle = "#fff";
      ctx.lineWidth = 2;
      let started = false;
      ctx.beginPath();
      for(let i=0;i<n;i++){
        const v = arr[i];
        if(!isFinite(v)) continue;
        const x = mapX(i);
        const y = mapY(v);
        if(!started){ ctx.moveTo(x,y); started = true; }
        else ctx.lineTo(x,y);
      }
      ctx.stroke();

      ctx.fillStyle = "#fff";
      for(let i=0;i<n;i++){
        const v = arr[i];
        if(!isFinite(v)) continue;
        const x = mapX(i);
        const y = mapY(v);
        ctx.beginPath(); ctx.arc(x,y,2.2,0,Math.PI*2); ctx.fill();
      }
    }

    function drawLineChartForecast(canvasId, history, forecast, yUnit, dtMin){
      const c = $(canvasId);
      if(!c) return;

      const hist = Array.isArray(history) ? history : [];
      const fore = Array.isArray(forecast) ? forecast : [];
      const combined = hist.concat(fore);
      if(combined.length < 2) return;

      const H = 200;
      const {ctx, w, h} = resizeCanvas(c, H);
      ctx.clearRect(0,0,w,h);

      const arr = combined.map(v => (v===null || v===undefined) ? NaN : Number(v));
      const valid = arr.filter(v => isFinite(v));
      if(valid.length < 2) return;

      let min = Math.min(...valid);
      let max = Math.max(...valid);
      let pad = (max - min) * 0.12;
      if(pad === 0) pad = 1;
      min -= pad; max += pad;

      ctx.fillStyle = "#fff";
      ctx.font = "12px Courier New";

      const yLabels = [];
      for(let i=0;i<=4;i++){
        const val = (max - (max-min) * (i/4));
        const txt = (Math.abs(val) >= 100 ? val.toFixed(0) : val.toFixed(1)) + " " + yUnit;
        yLabels.push(txt);
      }
      const maxLabelW = Math.max(...yLabels.map(t => ctx.measureText(t).width));

      const mL = Math.max(48, Math.ceil(maxLabelW) + 12);
      const mR = 12, mT = 10, mB = 30;

      const plotW = Math.max(10, w - mL - mR);
      const plotH = Math.max(10, h - mT - mB);

      const n = arr.length;
      const zeroIndex = Math.max(0, hist.length - 1);

      function mapX(i){ return mL + plotW * (i/(n-1)); }
      function mapY(v){ return mT + plotH - plotH * ((v - min) / (max - min)); }

      const ticks = [];
      ticks.push(0);
      ticks.push(Math.round(zeroIndex/2));
      ticks.push(zeroIndex);
      ticks.push(Math.round((zeroIndex + (n-1))/2));
      ticks.push(n-1);
      const uniq = Array.from(new Set(ticks)).filter(i => i>=0 && i<=n-1).sort((a,b)=>a-b);

      ctx.strokeStyle = "#333";
      ctx.lineWidth = 1;
      for(let i=0;i<=4;i++){
        const y = mT + (plotH * i / 4);
        ctx.beginPath(); ctx.moveTo(mL,y); ctx.lineTo(mL+plotW,y); ctx.stroke();
      }
      for(const idx of uniq){
        const x = mapX(idx);
        ctx.beginPath(); ctx.moveTo(x,mT); ctx.lineTo(x,mT+plotH); ctx.stroke();
      }

      ctx.fillStyle = "#fff";
      ctx.font = "12px Courier New";

      ctx.textAlign = "right";
      ctx.textBaseline = "middle";
      for(let i=0;i<=4;i++){
        const y = mT + (plotH * i / 4);
        ctx.fillText(yLabels[i], mL - 6, y);
      }

      ctx.textAlign = "center";
      ctx.textBaseline = "top";
      for(const idx of uniq){
        const x = mapX(idx);
        const mins = (idx - zeroIndex) * (dtMin || DT_MIN);
        ctx.fillText(fmtTime(mins), x, mT + plotH + 6);
      }

      ctx.textAlign = "center";
      ctx.textBaseline = "bottom";
      ctx.fillText("czas", mL + plotW/2, h - 2);

      const x0 = mapX(zeroIndex);
      ctx.strokeStyle = "#666";
      ctx.lineWidth = 1;
      ctx.setLineDash([4,4]);
      ctx.beginPath(); ctx.moveTo(x0, mT); ctx.lineTo(x0, mT + plotH); ctx.stroke();
      ctx.setLineDash([]);

      ctx.strokeStyle = "#EFBF04";
      ctx.lineWidth = 2;
      let started = false;
      ctx.beginPath();
      for(let i=0;i<=zeroIndex;i++){
        const v = arr[i];
        if(!isFinite(v)) continue;
        const x = mapX(i);
        const y = mapY(v);
        if(!started){ ctx.moveTo(x,y); started = true; }
        else ctx.lineTo(x,y);
      }
      ctx.stroke();

      let lastHistIdx = -1;
      for(let i=zeroIndex;i>=0;i--){
        if(isFinite(arr[i])) { lastHistIdx = i; break; }
      }

      if(lastHistIdx >= 0){
        ctx.strokeStyle = "#1e5eff";
        ctx.lineWidth = 2;
        ctx.setLineDash([6,4]);
        ctx.beginPath();
        ctx.moveTo(mapX(lastHistIdx), mapY(arr[lastHistIdx]));
        for(let i=lastHistIdx+1;i<n;i++){
          const v = arr[i];
          if(!isFinite(v)) continue;
          ctx.lineTo(mapX(i), mapY(v));
        }
        ctx.stroke();
        ctx.setLineDash([]);
      }

      for(let i=0;i<n;i++){
        const v = arr[i];
        if(!isFinite(v)) continue;
        const x = mapX(i);
        const y = mapY(v);
        ctx.fillStyle = (i <= zeroIndex) ? "#EFBF04" : "#1e5eff";
        ctx.beginPath(); ctx.arc(x,y,2.2,0,Math.PI*2); ctx.fill();
      }
    }

    async function refreshLatest(){
      try{
        const r = await fetch('/api/latest', {cache:'no-store'});
        if(!r.ok) return;
        const d = await r.json();
        if(!d.ok){
          [
            'bd_sun','bd_cloud','bd_cold','bd_wind','bd_rain',
            'bd_humid','bd_dry',
            'bd_batt_low','bd_batt_crit',
            'bd_pres_low','bd_pres_high'
          ].forEach(id => showBadge(id,false));
          return;
        }

        $('last').textContent = `${pad2(d.h)}:${pad2(d.m)} | ${pad2(d.day)}.${pad2(d.mon)}.20${pad2(d.yr)}`;

        const temp = Number(d.temp) || 0;
        const presPa = Number(d.presPa) || 0;
        const hum = Number(d.hum) || 0;
        const wind = Number(d.wind) || 0;
        const rainmV = Number(d.rainmV) || 0;
        const Batt_procent = Number(d.Batt_procent) || 0;
        const sunV = Number(d.sunV) || 0;

        $('temp').textContent = temp.toFixed(1);
        $('pres').textContent = (presPa/100.0).toFixed(0);
        $('hum').textContent  = hum.toFixed(0);

        const feels = calcFeelsLikeC(temp, hum, wind);
        $('feels').textContent = (isFinite(feels) ? feels : temp).toFixed(1);

        $('wind').textContent = wind.toFixed(1);
        $('Batt_procent').textContent = String(Math.round(Batt_procent));

        const TH_SUN_V = 3.0;
        const TH_CLOUD_V = 1.8;
        const TH_COLD_C = 5.0;
        const TH_WIND_MS = 6.0;

        const TH_RAIN_START = 100.0;
        const TH_RAIN_LIGHT = 300.0;
        const TH_RAIN_MED = 500.0;
        const TH_RAIN_HEAVY = 1200.0;

        const TH_HUM_HI = 70.0;
        const TH_HUM_LO = 30.0;

        const TH_BATT_LOW = 35.0;
        const TH_BATT_CRIT = 20.0;

        const TH_PRES_LOW = 1000.0;
        const TH_PRES_HIGH = 1020.0;

        const isSunny = sunV > TH_SUN_V;
        const isCloud = (!isSunny) && (sunV > TH_CLOUD_V);
        const isCold = temp < TH_COLD_C;
        const isWind = wind > TH_WIND_MS;
        const isRain = rainmV > TH_RAIN_START;

        const isHumid = hum >= TH_HUM_HI;
        const isDry = hum <= TH_HUM_LO;

        const isBattCrit = Batt_procent <= TH_BATT_CRIT;
        const isBattLow = (Batt_procent <= TH_BATT_LOW) && !isBattCrit;

        const presHpa = presPa / 100.0;
        const isPresLow = presHpa < TH_PRES_LOW;
        const isPresHigh = presHpa > TH_PRES_HIGH;

        let wetPct = 0;
        const denom = (rainWetMV - rainDryMV);
        if(denom > 10){
          wetPct = 100.0 * (rainmV - rainDryMV) / denom;
        }else{
          wetPct = 100.0 * (rainmV - TH_RAIN_START) / (TH_RAIN_HEAVY - TH_RAIN_START);
        }
        wetPct = clamp(wetPct, 0, 100);

        let rainState = "Brak";
        if(rainmV > TH_RAIN_START){
          if(rainmV > TH_RAIN_HEAVY) rainState = "Ulewa";
          else if(rainmV > TH_RAIN_MED) rainState = "Silny deszcz";
          else if(rainmV > TH_RAIN_LIGHT) rainState = "Deszcz";
          else rainState = "Mżawka";
        }
        $('rainState').textContent = `${rainState} (${wetPct.toFixed(0)}%)`;

        showBadge('bd_sun', isSunny);
        showBadge('bd_cloud', isCloud);
        showBadge('bd_cold', isCold);
        showBadge('bd_wind', isWind);
        showBadge('bd_rain', isRain);

        showBadge('bd_humid', isHumid);
        showBadge('bd_dry', isDry);

        showBadge('bd_batt_crit', isBattCrit);
        showBadge('bd_batt_low', isBattLow);

        showBadge('bd_pres_low', isPresLow);
        showBadge('bd_pres_high', isPresHigh);

      }catch(e){
        console.error(e);
      }
    }

    async function refreshHistory(){
      try{
        const r = await fetch('/api/history', {cache:'no-store'});
        if(!r.ok) return;
        const d = await r.json();
        if(!d.ok) return;

        drawLineChartForecast('chartTemp', d.temp || [], d.tempForecast || [], "°C", DT_MIN);

        // Wygładzenie dotyczy wyłącznie danych pokazywanych na wykresie baterii.
        // Wartość w tabeli i progi alarmowe nadal korzystają z aktualnego, nieprzefiltrowanego pomiaru.
        const BATT_MA_WINDOW = 5;
        drawLineChart('chartBatt', movingAverage(d.Batt_procent || [], BATT_MA_WINDOW), "%", DT_MIN);

      }catch(e){
        console.error(e);
      }
    }

    refreshLatest();
    refreshHistory();
    setInterval(refreshLatest, 2000);
    setInterval(refreshHistory, 10000);
  </script>
  </body>
  </html>
  )rawliteral";


struct PoprawionyCzas{
  int Day;
  int Month;
  int Year;
  int Hour;
  int Minute;
};

static void NTP_start(){
  if(ntp_uruchomiony || WiFi.status() != WL_CONNECTED) return;

  configTzTime(NTP_TZ, NTP_SERVER_1, NTP_SERVER_2, NTP_SERVER_3);
  ntp_uruchomiony = true;
  Serial.println("NTP: rozpoczecie synchronizacji");
}

static bool NTP_pobierz_czas(struct tm& czasLokalny){
  if(!ntp_uruchomiony) return false;

  time_t teraz = time(nullptr);
  if(teraz < NTP_MIN_VALID_EPOCH) return false;
  return localtime_r(&teraz, &czasLokalny) != nullptr;
}
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
void loop(){
  server.handleClient();
  Internet_check_loop();
  NTP_loop();
  mqttLoop();
  MQTT_publish_loop();
  SD_logger_loop();

  delay(2);
}

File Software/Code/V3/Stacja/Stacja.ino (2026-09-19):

#include <Wire.h>
#include <Adafruit_Sensor.h>
#include <Adafruit_BME280.h>
#include <Adafruit_SGP40.h>
#include <Rtc_Pcf8563.h>
#include <WiFi.h>
#include <esp_now.h>
#include "driver/rtc_io.h"
#include "PogodynkaTypes.h"
#define RTC_FORCE_SET_ON_BOOT 0
Adafruit_BME280 bme;
Adafruit_SGP40  sgp;
Rtc_Pcf8563     rtc;
const int RTC_INT_PIN = 27;      
uint8_t peerAddress[] = {0x28, 0x56, 0x2F, 0x71, 0x92, 0x34};
esp_now_peer_info_t peerInfo;
const uint8_t SET_DAY   = 19;
const uint8_t SET_WDAY  = 7;
const uint8_t SET_MONTH = 9;
const uint8_t SET_CENT  = 0;
const uint8_t SET_YEAR  = 26;
const uint8_t SET_HOUR  = 22;
const uint8_t SET_MIN   = 9;
const uint8_t SET_SEC   = 0;
bool bme_ok = false;
const int Hall_pin          = 17;
const int WaterSensor       = 19;
const int WaterSensorAnalog = 34;
const int Battery_level     = 35;
const int Fotopanel_level   = 33;
const float Resistor_division =2.0f;
const int baudrate = 9600;
const float ramie = 0.096f; // ~10 cm
volatile uint32_t  Hall_count = 0;
const uint32_t pomiar_predkosci_czas =10; //sec
uint16_t Minuty_sleep=30;
uint8_t Measurments_mean = 5;
const int Power_peryf   = 25;
Dane_ESP Dane;


bool BME_init() {
  if (!bme.begin(0x76)) {
    return false;
  }
  return true;
}
double Temperature(){
  double value=0.0f;
  for(int i=0;i<Measurments_mean;i++){ 
    value += bme.readTemperature() ;}
    return value/Measurments_mean;
}
double Humility(){
  double value=0.0f;
  for(int i=0;i<Measurments_mean;i++){ 
    value += bme.readHumidity() ;}
    return value/Measurments_mean;
}
double Pressure(){
  double value=0.0f;
  for(int i=0;i<Measurments_mean;i++){ 
    value += bme.readPressure() ;}
    return value/Measurments_mean;
}
float Rain_level() {
  if(digitalRead(WaterSensor)==false){
    float value=0.0f;
    for(int i=0;i<Measurments_mean;i++){ 
      value += analogReadMilliVolts(WaterSensorAnalog);}
      return value/Measurments_mean;}
  return 0.0f;
}
float Battery_state() {
  float value=0.0f;
  for(int i=0;i<Measurments_mean;i++) {value += analogReadMilliVolts(Battery_level)*Resistor_division;}
  return value/Measurments_mean;
}
float Sun_state() {
  float value=0.0f;
  for(int i=0;i<Measurments_mean;i++) {value += analogReadMilliVolts(Fotopanel_level)*Resistor_division;}
  return value/Measurments_mean;
}
float Wind_speed(){
  unsigned long time_start, time_end;
  float omega, speed;
  uint32_t start_hall = Hall_count;
  time_start = millis();
  while(true){
    time_end = millis() - time_start;
    if (time_end>=pomiar_predkosci_czas*1000.0f){
        uint32_t last_hall = Hall_count;
        omega = ((last_hall-start_hall) * 2.0f * PI) / (time_end/1000.0f);
        speed = omega * ramie;
        return speed;
    }
    delay(50);
  }
}


void OnDataSent(const uint8_t *mac_addr, esp_now_send_status_t status) {
  Serial.print("\r\nLast Packet Send Status:\t");
  Serial.println(status == ESP_NOW_SEND_SUCCESS ? "Delivery Success" : "Delivery Fail");
}
        
void IRAM_ATTR HallISR() {Hall_count++;}

void setup() {
  Serial.begin(baudrate);
  Wire.begin();

#if RTC_FORCE_SET_ON_BOOT
  rtc.initClock();
  rtc.setDate(SET_DAY, SET_WDAY, SET_MONTH, SET_CENT, SET_YEAR);
  rtc.setTime(SET_HOUR, SET_MIN, SET_SEC);
  while (true) {
    delay(1000);
  }
#endif

  pinMode(RTC_INT_PIN, INPUT_PULLUP);
  rtc.clearAlarm();
  bme_ok = BME_init();
  pinMode(Hall_pin, INPUT);
  attachInterrupt(digitalPinToInterrupt(Hall_pin), HallISR, RISING);
  pinMode(WaterSensor, INPUT);
  pinMode(Power_peryf, OUTPUT);
  pinMode(WaterSensorAnalog, INPUT);
  pinMode(Fotopanel_level, INPUT);
  pinMode(Battery_level, INPUT);
  analogReadResolution(12);
  analogSetPinAttenuation(WaterSensorAnalog, ADC_11db);
  analogSetPinAttenuation(Battery_level, ADC_11db);
  analogSetPinAttenuation(Fotopanel_level, ADC_11db);
  digitalWrite(Power_peryf, LOW);
  esp_sleep_enable_ext0_wakeup((gpio_num_t)RTC_INT_PIN, 0);
}


void loop() {
digitalWrite(Power_peryf, HIGH);
delay(10);
Pomiar();
Send_dane();
RTC_set_alarm();
digitalWrite(Power_peryf, LOW);
esp_deep_sleep_start();
}
//~10mA sleep
//~90mA pomiary
//~200mA sending


void Pomiar(){
  Dane.Day=rtc.getDay();
  Dane.Month=rtc.getMonth();
  Dane.Year=rtc.getYear();
  Dane.Hour=rtc.getHour();
  Dane.Minute=rtc.getMinute();
    Dane.Rain=Rain_level();
    Dane.Battery_level=Battery_state();
    Dane.Sun_level=Sun_state();
  if(bme_ok){
    Dane.Temperature=Temperature();
    Dane.Pressure=Pressure();
    Dane.Humility=Humility();
  }
  Dane.Wind_speed=Wind_speed();
}
void RTC_set_alarm() {
  uint16_t Aktualna_godzina = rtc.getHour();
  uint16_t Aktualna_minuta  = rtc.getMinute();

  uint32_t total = Aktualna_godzina * 60u + Aktualna_minuta;

  total = ((total / 30u) + 1u) * 30u;
  total %= 24u * 60u;

  uint16_t Alarm_hour = total / 60u;
  uint16_t alarm_min  = total % 60u;

  rtc.clearAlarm();
  rtc.setAlarm(alarm_min, Alarm_hour, 99, 99);
  rtc.enableAlarm();
}
void Send_dane(){
  WiFi.mode(WIFI_STA);
  delay(200); //niech sie ustali
  esp_err_t err = esp_now_init();
  if(err != ESP_OK){delay(5000);esp_now_init();}
  esp_now_register_send_cb(OnDataSent);
  memcpy(peerInfo.peer_addr, peerAddress, 6);
  peerInfo.channel = 0;
  peerInfo.encrypt = false;
  if (esp_now_add_peer(&peerInfo) != ESP_OK){
    Serial.println("Failed to add peer");
    WiFi.mode(WIFI_OFF);
    return;}

  esp_err_t result = esp_now_send(peerAddress, (uint8_t *) &Dane, sizeof(Dane));
  /*
    if (result == ESP_OK) {
      Serial.println("Sent with success");
    }
    else {
      Serial.println("Error sending the data");
    }
  */
  delay(500);
  WiFi.mode(WIFI_OFF);
}

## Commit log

2026-08-31 Add status topic and RTC boot-time set option
    MQTT: introduce TOPIC_STATUS (MQTT_ROOT "/status") so receiver can publish node status. Stacja: enable RTC_FORCE_SET_ON_BOOT and add code in setup() to initialize and set the PCF8563 RTC using update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
2026-09-19 Small fixes after flooding
    Due to a fault that arose following a week of rain, it was necessary to carry out a number of physical repairs. Unfortunately, the battery connector and the solar panel connector were connected the wrong way round. The system is functioning as intended, but the measurement terminals have been swapped.
    [Stacja.ino]
